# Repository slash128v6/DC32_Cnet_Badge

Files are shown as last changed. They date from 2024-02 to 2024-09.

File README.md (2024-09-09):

# DC32 CompuNet Badge 
## Description
The **Fony Bitman** by CompuNet is a cutting-edge, compact, and highly versatile device designed to seamlessly integrate with modern lifestyles. This device harnesses the robust capabilities of the ESP32 microcontroller, known for its high performance, low power consumption, and advanced wireless connectivity features.

*Key Features:*

Arduino-based ESP32 Microcontroller: At its core, the **Fony Bitman** features Wi-Fi and Bluetooth connectivity, as well as high-fidelity mono sound with redundant output (a second speaker).

Customizable and Expandable: The **Fony Bitman** by CompuNet is highly customizable, allowing developers to create tailored applications and features. Its expandable nature supports various sensors and modules, enhancing functionality for specific use cases. If you don't like how it works, re-engineer accordingly.

This device is not UL listed, certified, warranteed or recommended for anyone that is adverse to sharp, dangerous objects. As with all electronics projects, unplug when not in use and store safely to avoid fires, spontanious combustion, itching or burning sensations. 

Do not taunt the **Fony Bitman**.

## Badge Operation

The power switch selects battery power or USB power. USB power will charge the battery. The battery must be sufficiently charged for battery operation. If the badge does not operate on battery power let it charge via USB. There is a battery “gas gauge” on the charge module that is viewable from the front of the board.

From your phone connect to Bluetooth device “FONY BITMAN”. Sound should play through the speakers and the LED strips should react to the music. The touch pads on the top front of the badge should act as music and volume controls.

## Part 1: Badge Assembly

### Badge Parts List

| QTY | Description |
|-----|---|
| 1 | 2 pos CONN HEADER  |
| 1 | switch |
| 1 | 6 pos CONN HEADER  |
| 1 | 16 pos CONN HEADER |
| 1 | ESP-32 |
| 2 | LED Stick |
| 1 | Amp |
| 2 | speaker |
| 1 | charge module |
| 3 | foam tape |
| 1 | battery |

### Step 1: Front view:

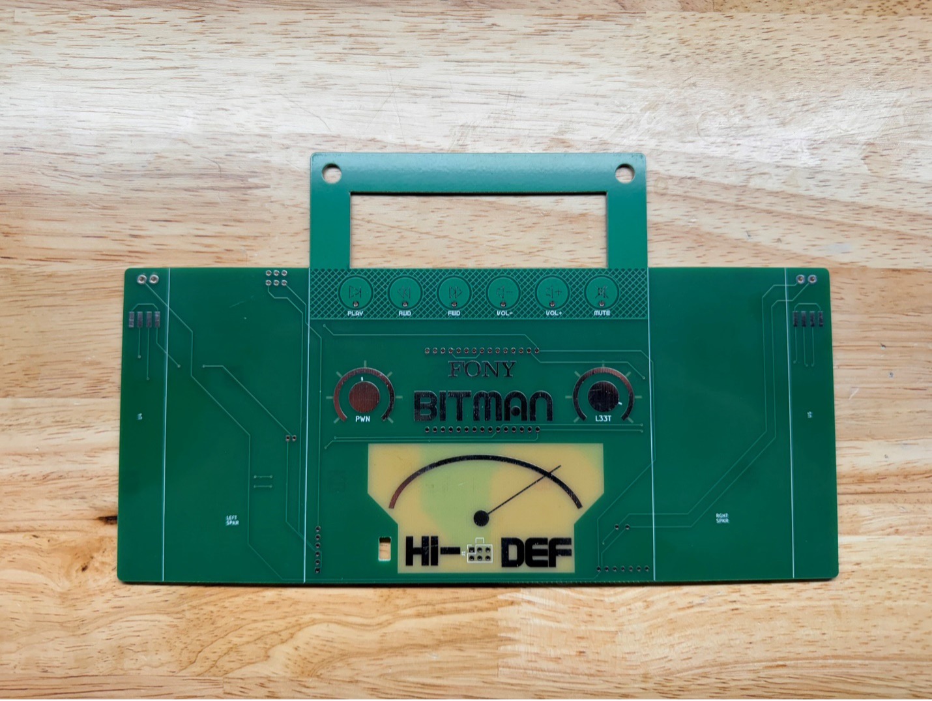
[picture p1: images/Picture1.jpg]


### Step 2: Rear View

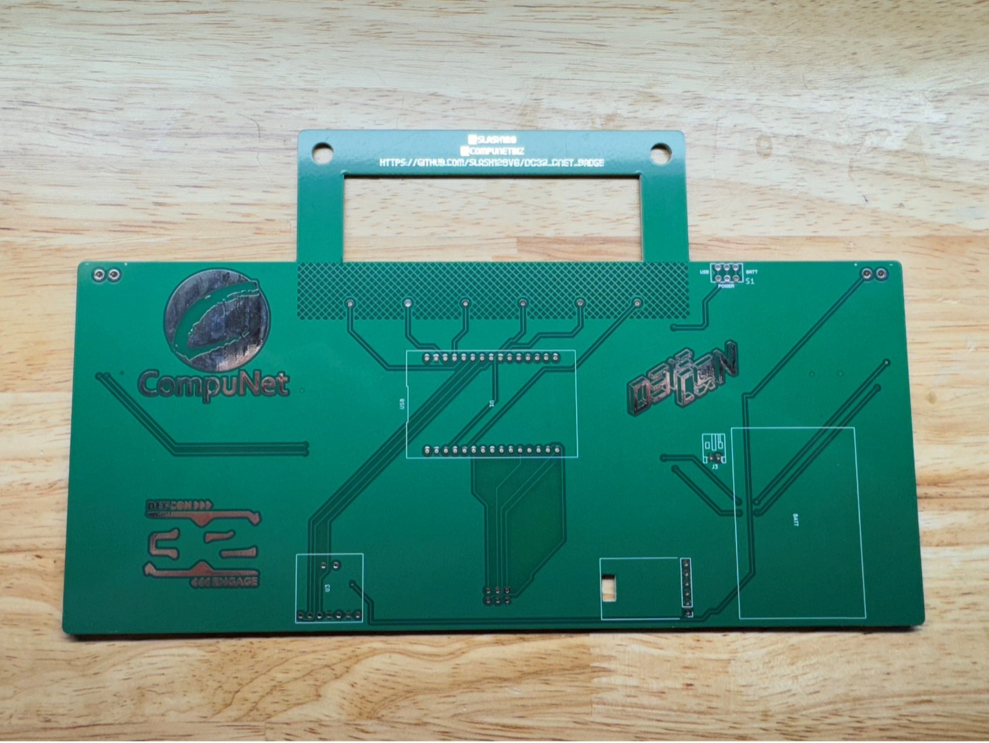
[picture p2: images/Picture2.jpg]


### Step 3: Solder LED strips to front

The DI (Data In) side connects to the badge pads.

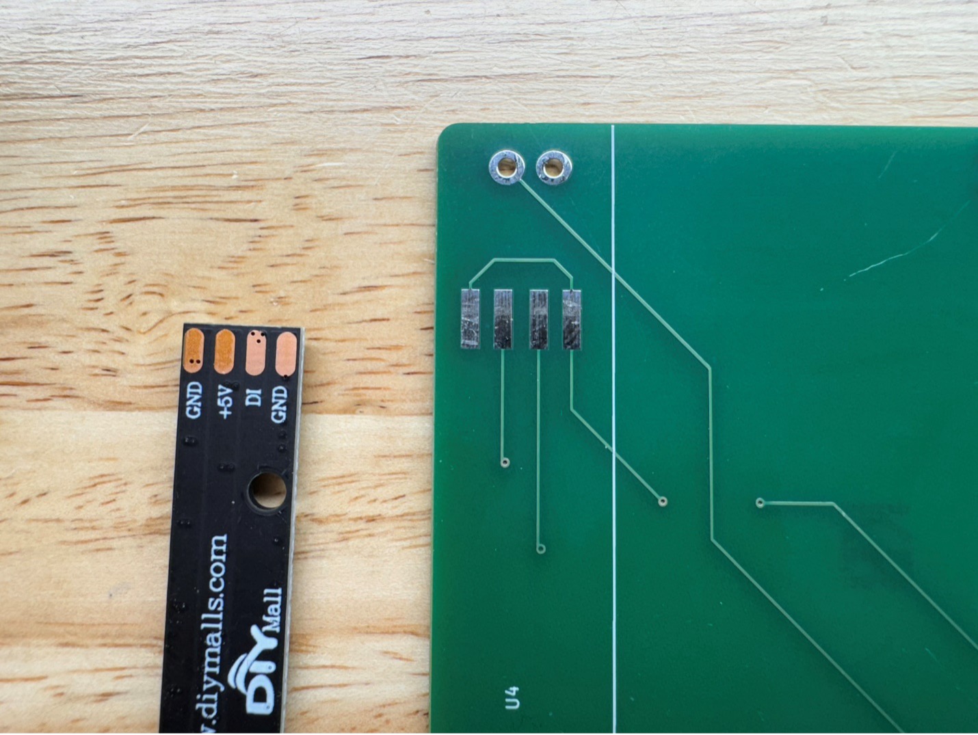
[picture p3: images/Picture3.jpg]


### Step 4: Tin the LED & badge pads

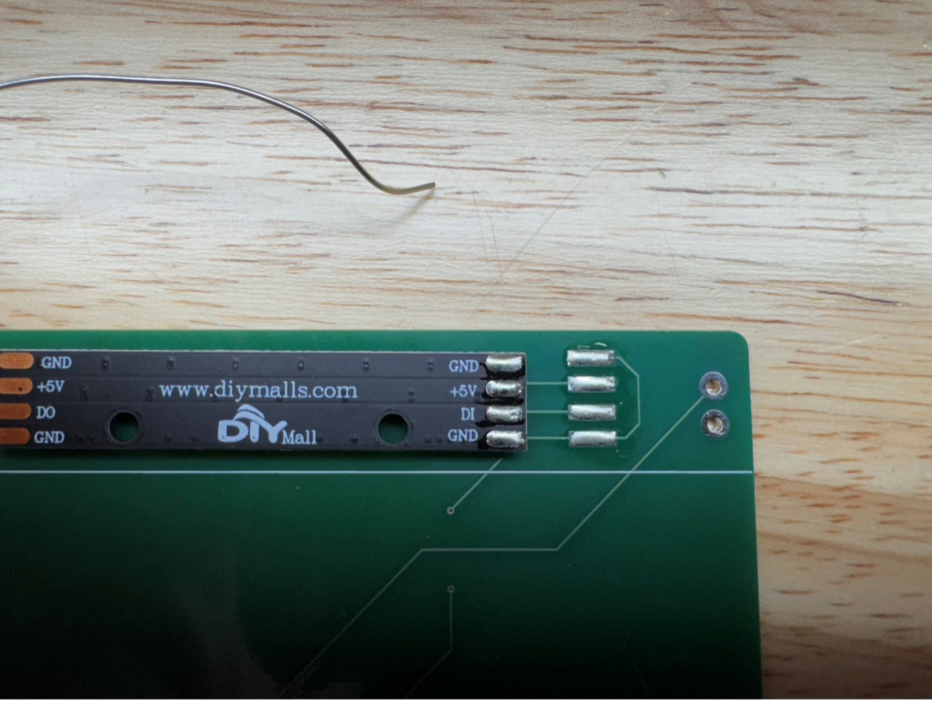
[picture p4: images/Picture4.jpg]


### Step 5: Apply first LED

Line up the LED strip pads on the badge pads leaving the ends of the badge pads exposed so you can heat them up with your soldering iron. It’s a little tricky but you should be able to get the solder to flow and insert some solder from the sides of the pads to connect the pads. Try to keep the LED strip straight. 

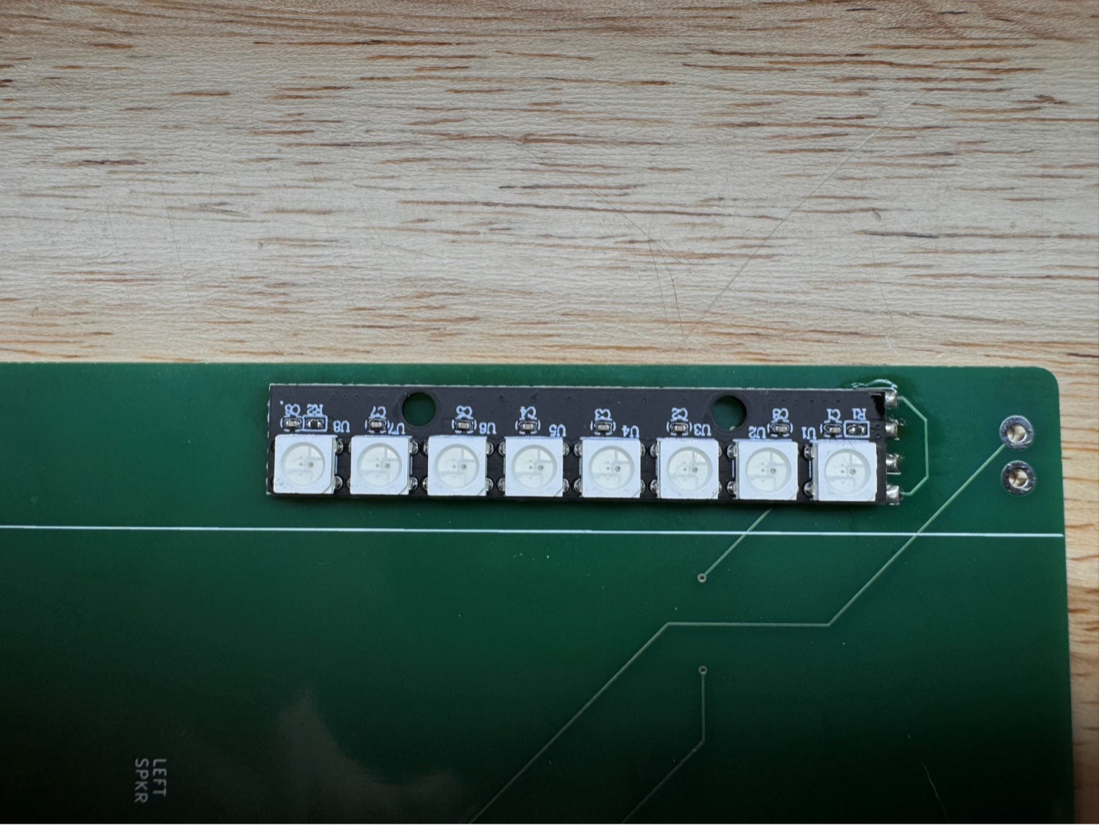
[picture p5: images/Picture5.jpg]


### Step 6: Repeat for the second LED strip

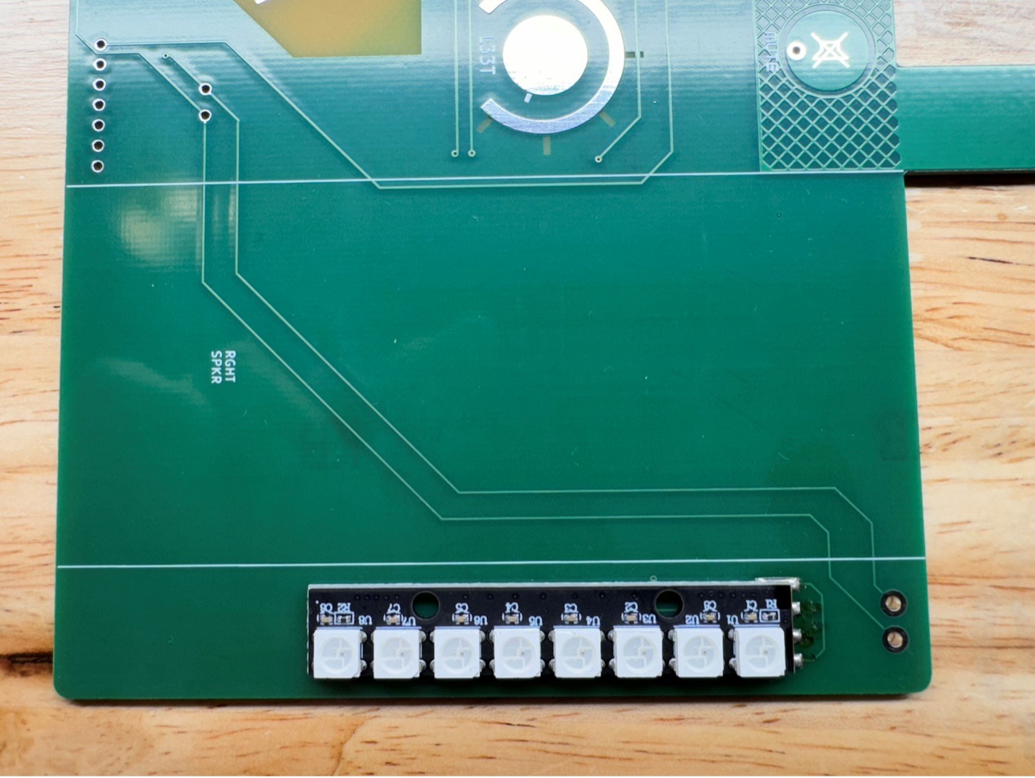
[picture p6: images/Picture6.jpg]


### Step 7: Power Switch

Solder the power switch on the back with the switch tab facing up

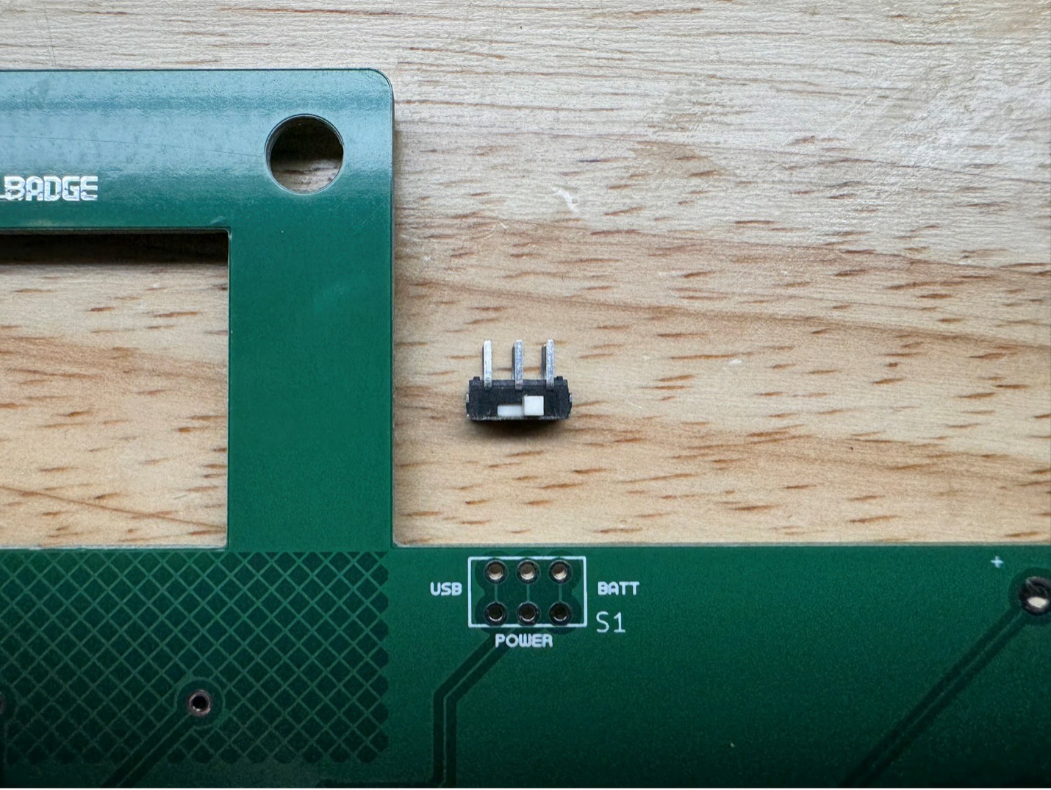
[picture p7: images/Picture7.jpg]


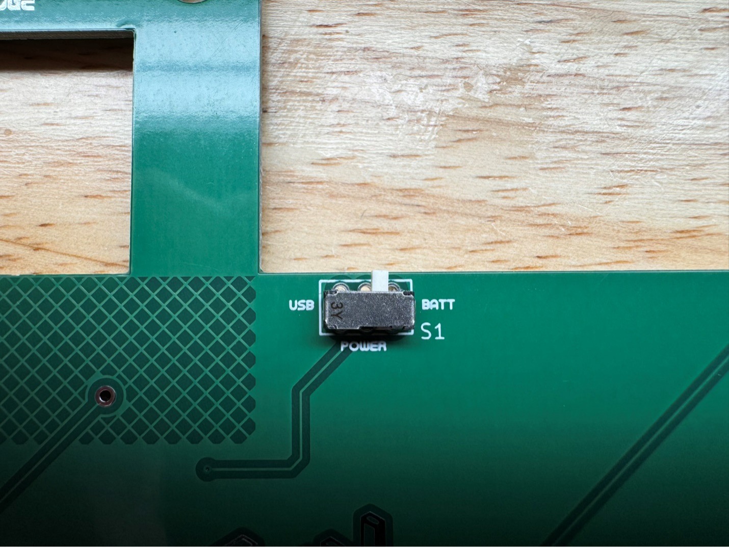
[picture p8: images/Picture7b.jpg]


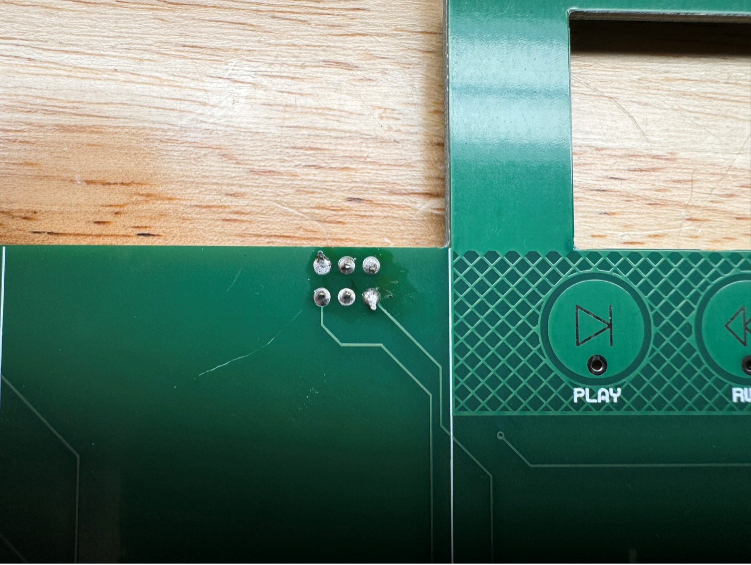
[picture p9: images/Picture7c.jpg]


### Step 8: Solder the SAO connector

Solder the SAO connector with the tab up matching the outline keeping it straight and parallel to the bottom oedge of the badge

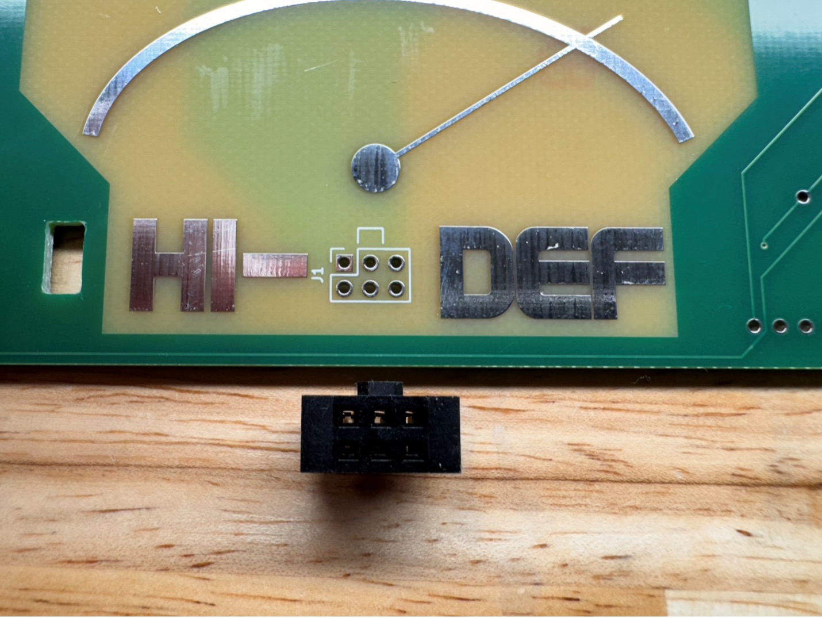
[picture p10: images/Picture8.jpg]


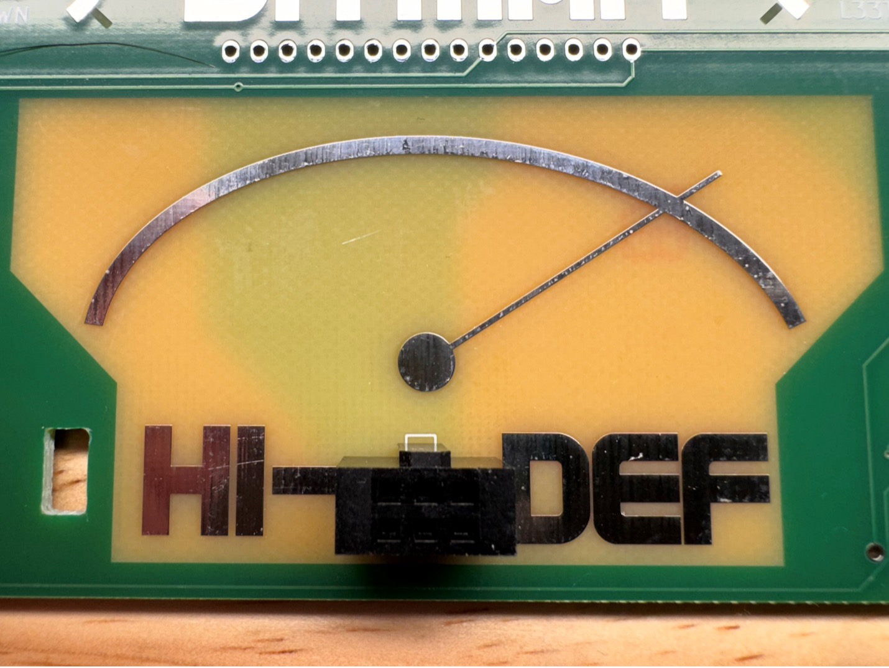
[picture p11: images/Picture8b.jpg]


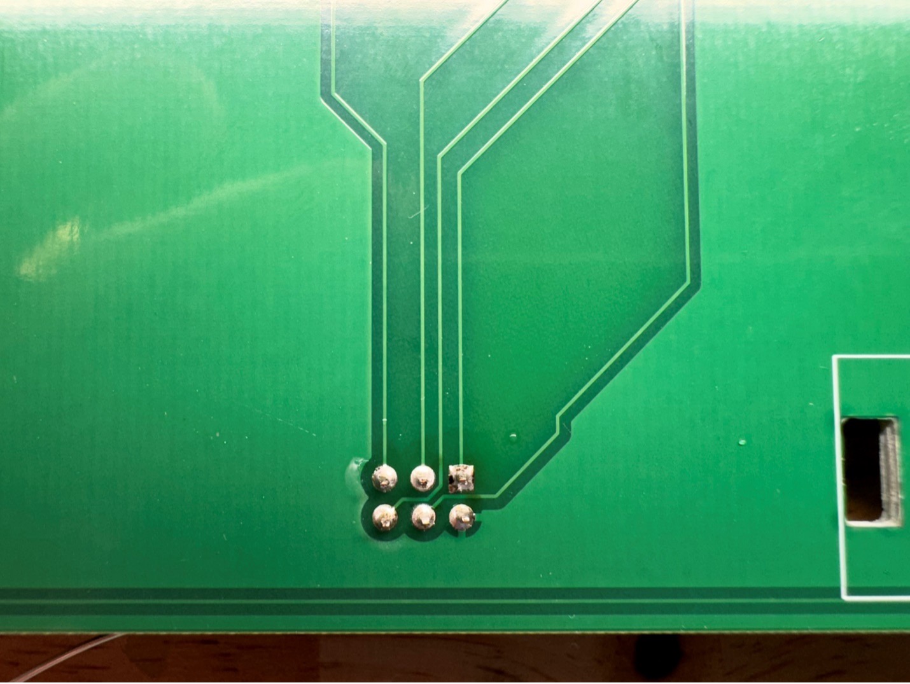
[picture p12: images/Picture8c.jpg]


### Step 9: Battery Charger Module

Locate the battery charger module and pin header and cut off 6 pins

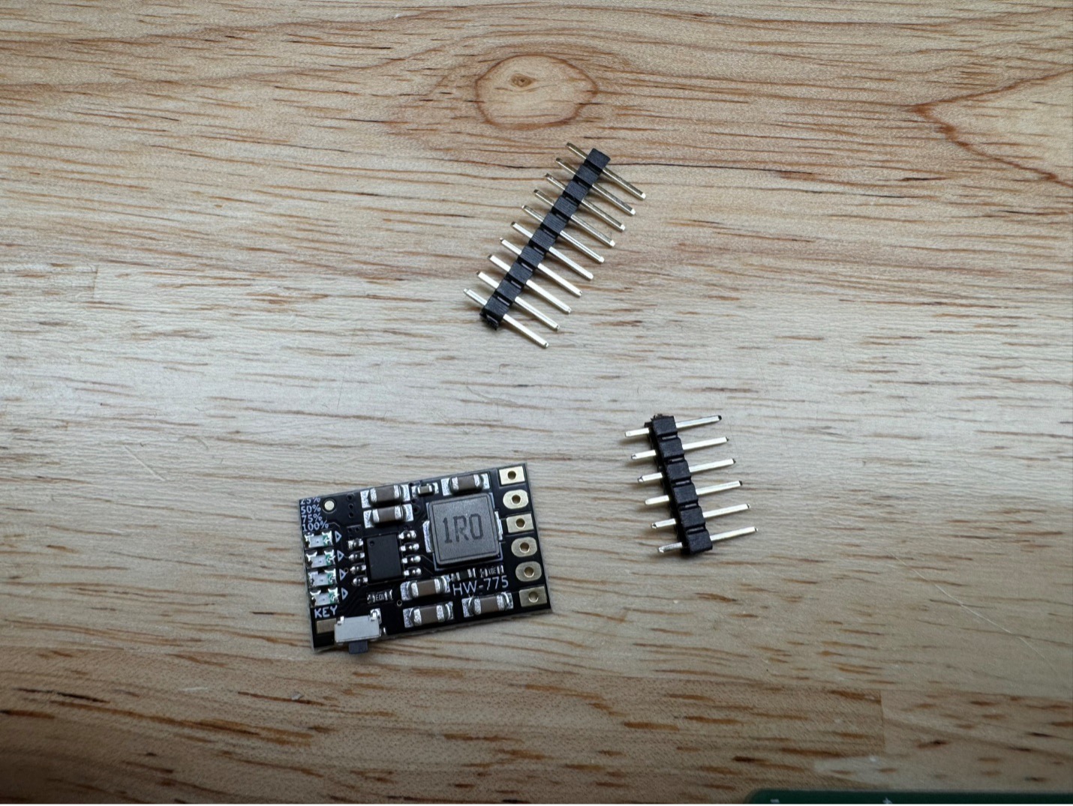
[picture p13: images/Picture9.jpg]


### Step 10: Solder the module header

Solder the 6 pin header to the charge module with the short pins protruding through the white silkscreen side of the charge module

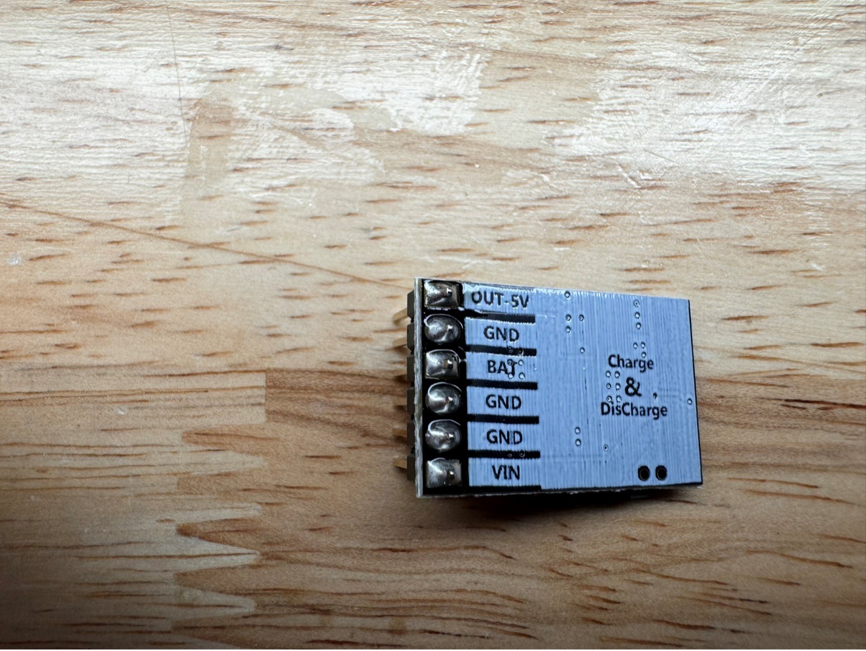
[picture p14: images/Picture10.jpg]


### Step 11: Attach module to the badge

Solder the charge module to the back of the badge

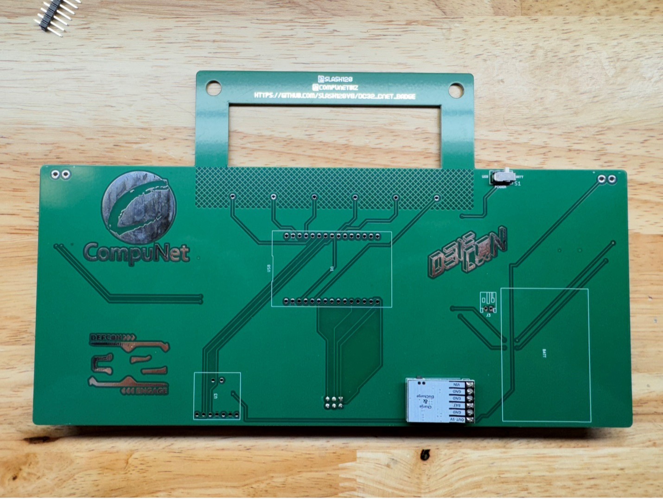
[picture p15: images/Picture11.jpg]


### Step 12: Verify LED visibility

The charge module battery level LEDs should be visibile through the front of the badge

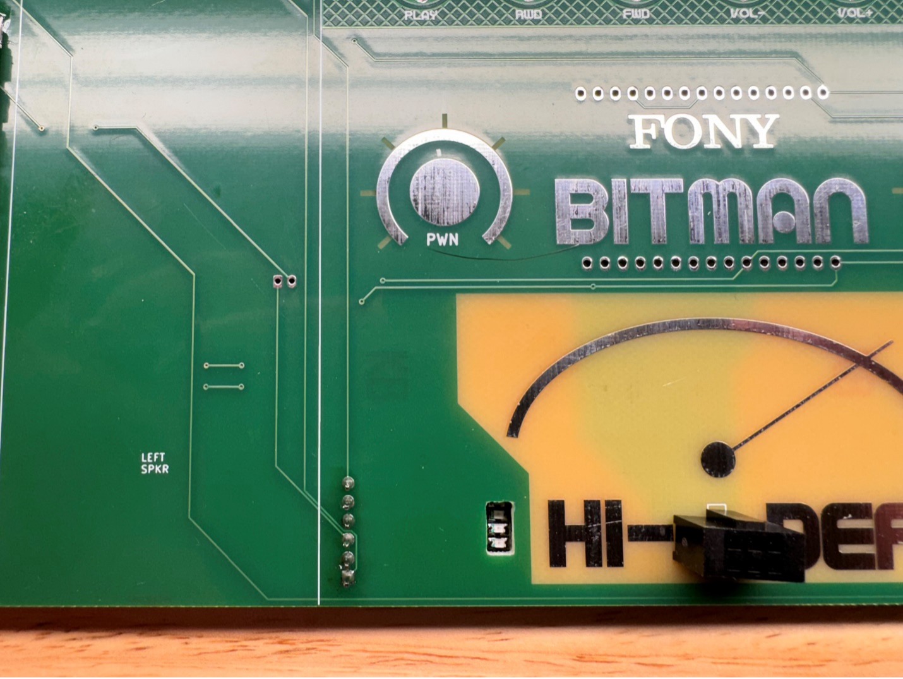
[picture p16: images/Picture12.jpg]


### Step 13: Amplifier module

Locate the amplifier module and pin header, the green screw terminal is not needed and can be discarded

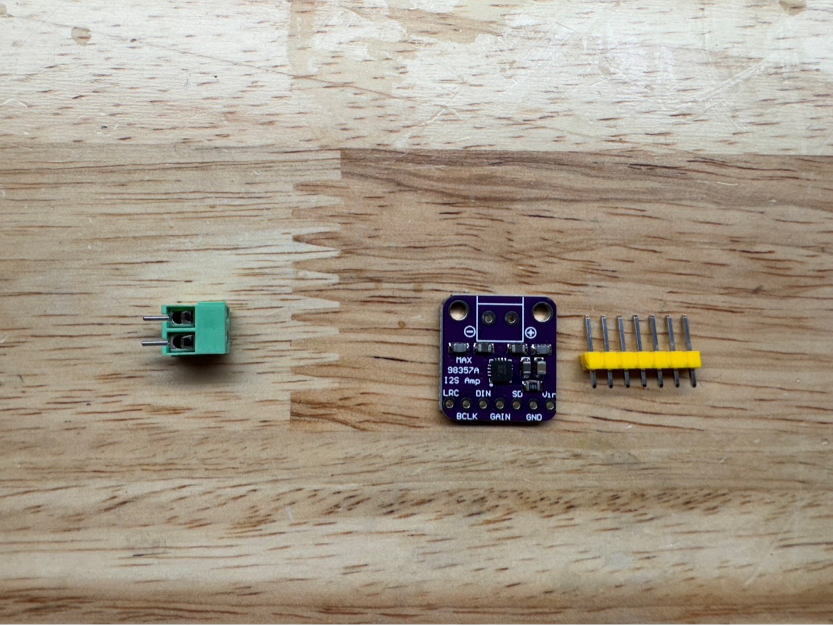
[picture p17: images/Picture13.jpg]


### Step 14: Solder amp header

Solder the pin header to the amplifier with the short side of the pins protruding through the silkscreen pin label side of the amplifier module

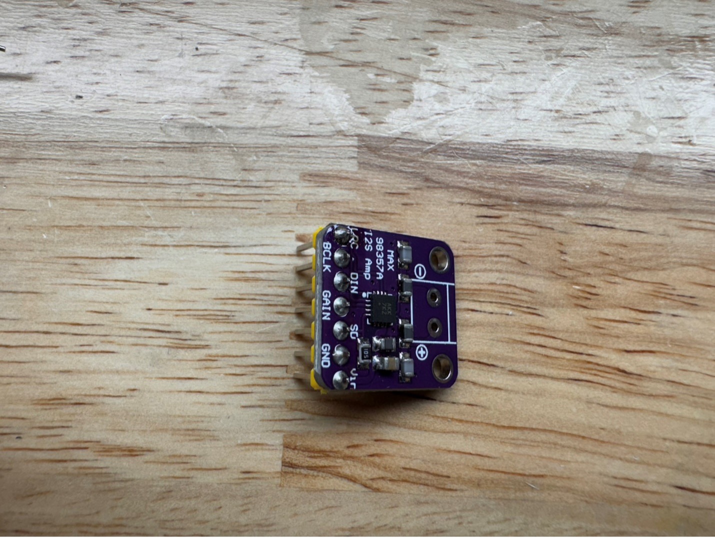
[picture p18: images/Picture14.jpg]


### Step 15: Attach pins to speaker outs

15)	Cut 2 more single pins and solder them to the speaker outputs with the short side protruding through the silkscreen pin label side of the amplifier module

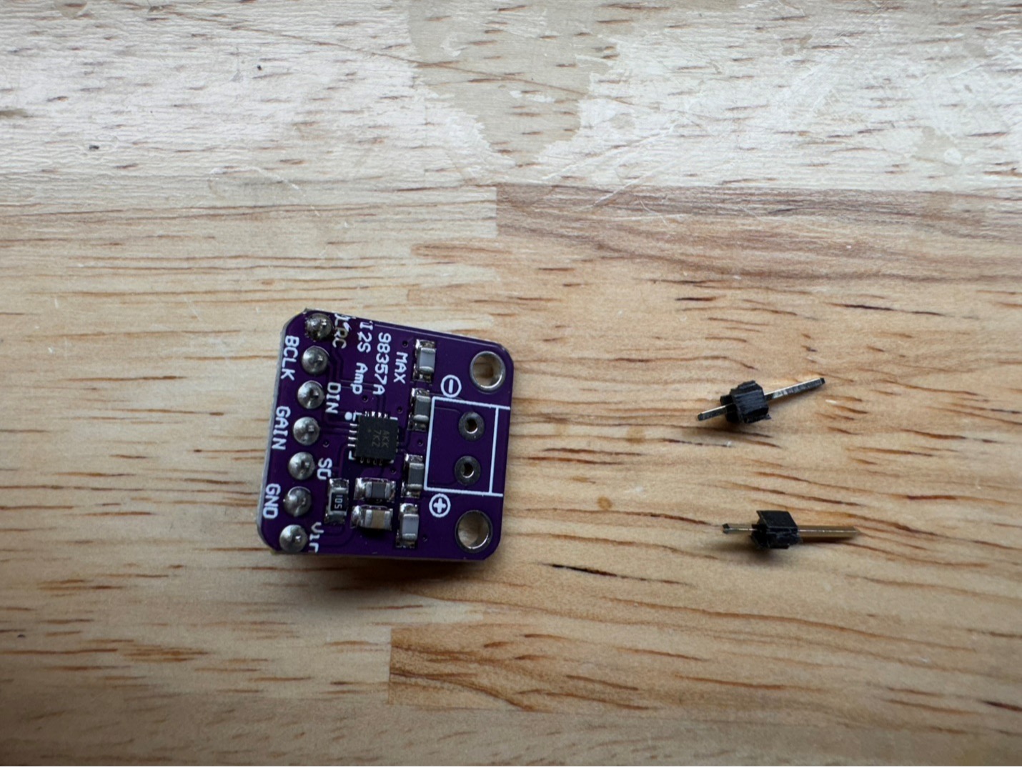
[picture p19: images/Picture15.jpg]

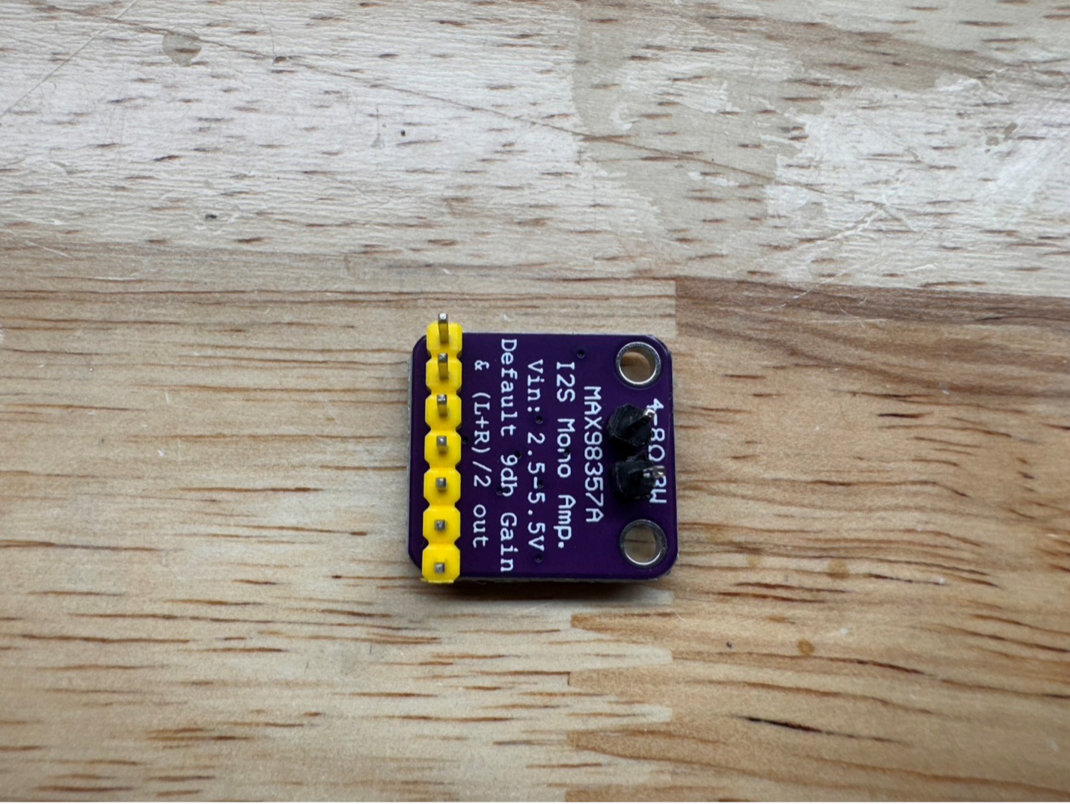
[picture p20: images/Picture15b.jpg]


### Step 16: Attach amp module to badge

Solder the amplifier module through the back of the badge

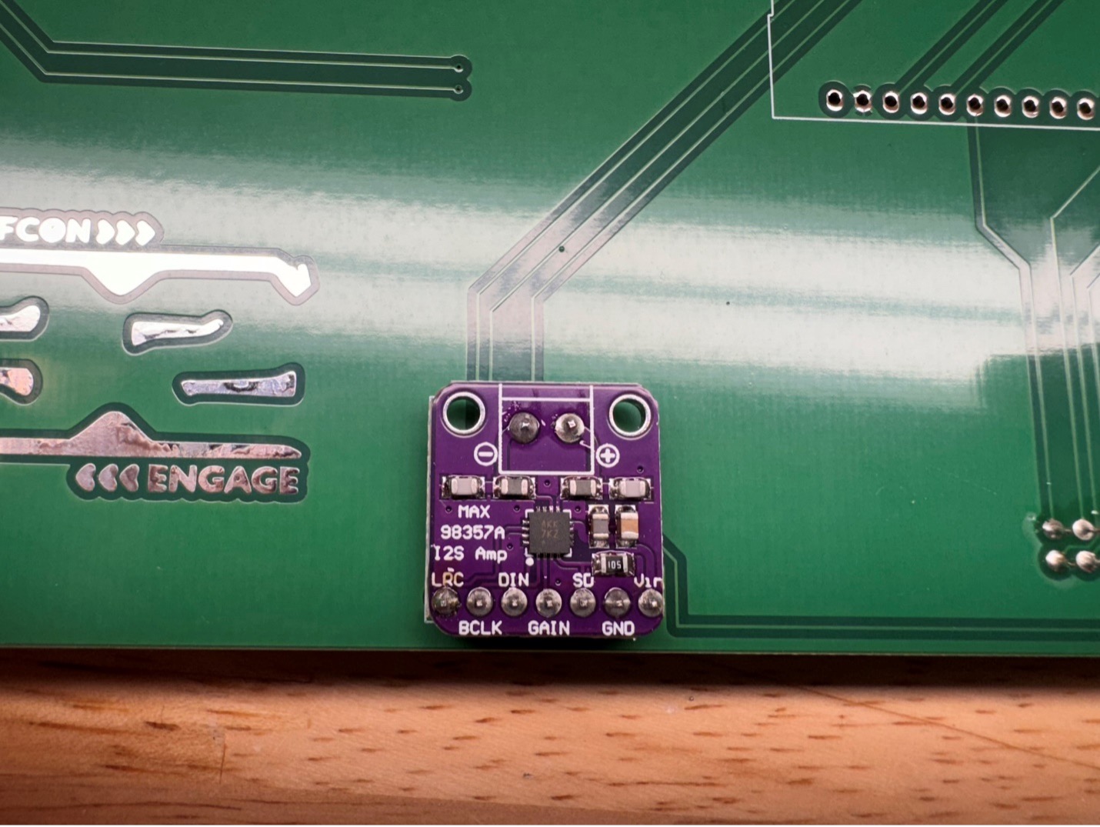
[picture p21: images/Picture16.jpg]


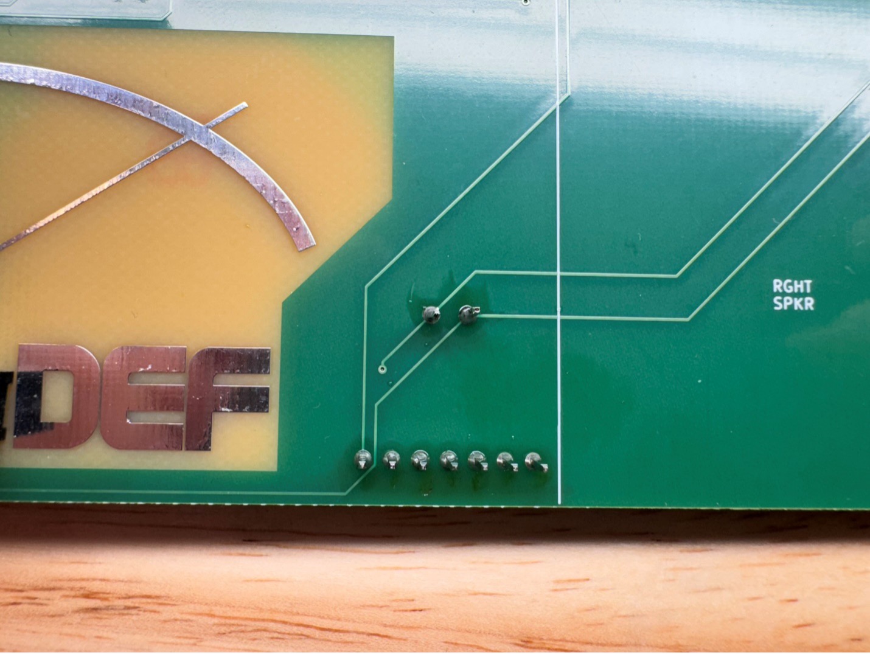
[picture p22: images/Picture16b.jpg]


### Step 17: ESP32 Module

Solder the ESP32 module to the back of the badge with the USB connector oriented to the silkscreen outline which should face the CompuNet logo

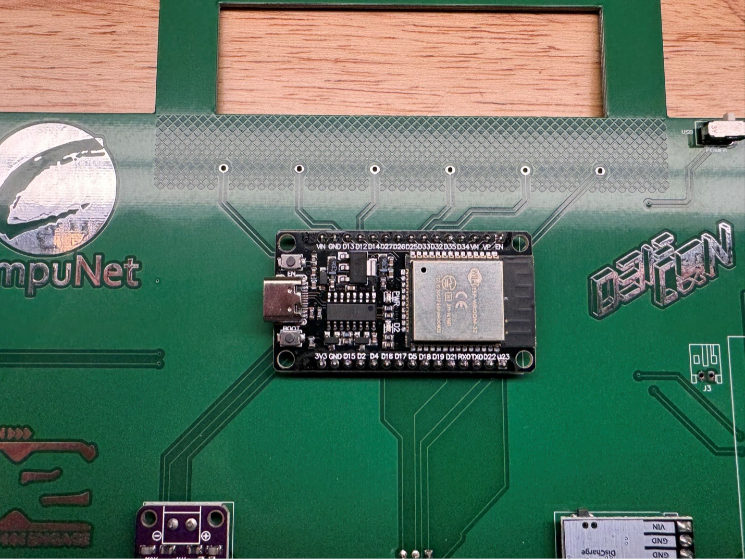
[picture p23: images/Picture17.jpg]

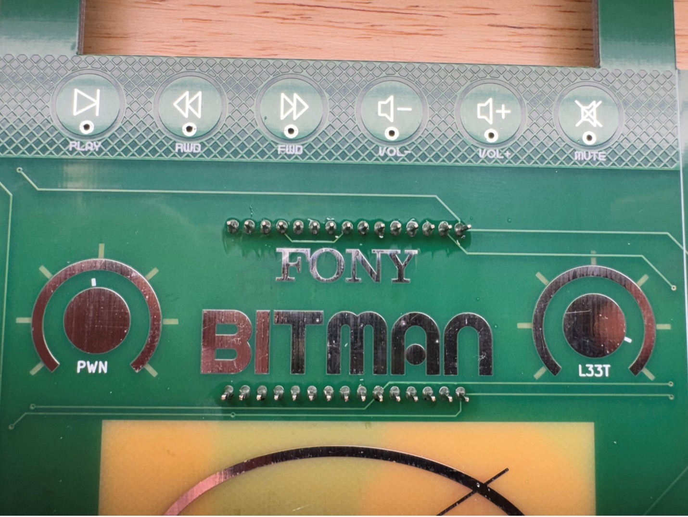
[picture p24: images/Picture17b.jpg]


### Step 18: Battery Connector

Solder the battery connector to the back of the badge

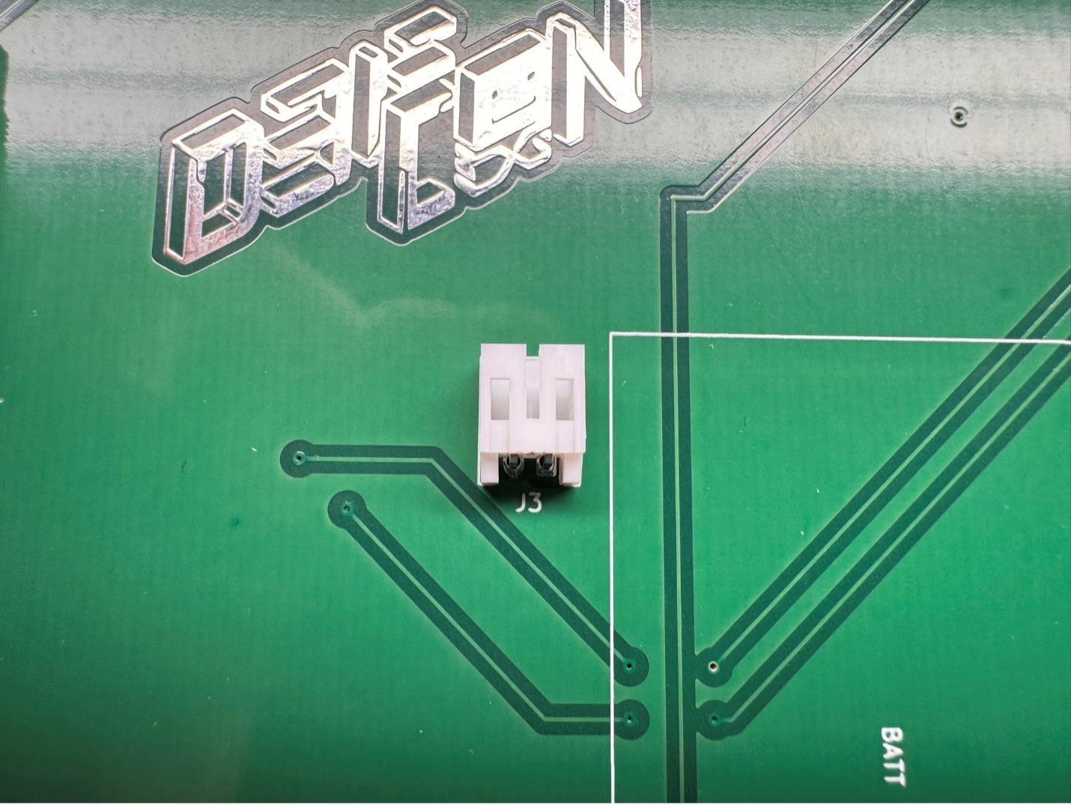
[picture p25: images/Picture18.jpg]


### Step 19: Speaker Wire

Trim the speaker wires leaving a few inches and run the speaker wires through the holes as shown for strain relief 

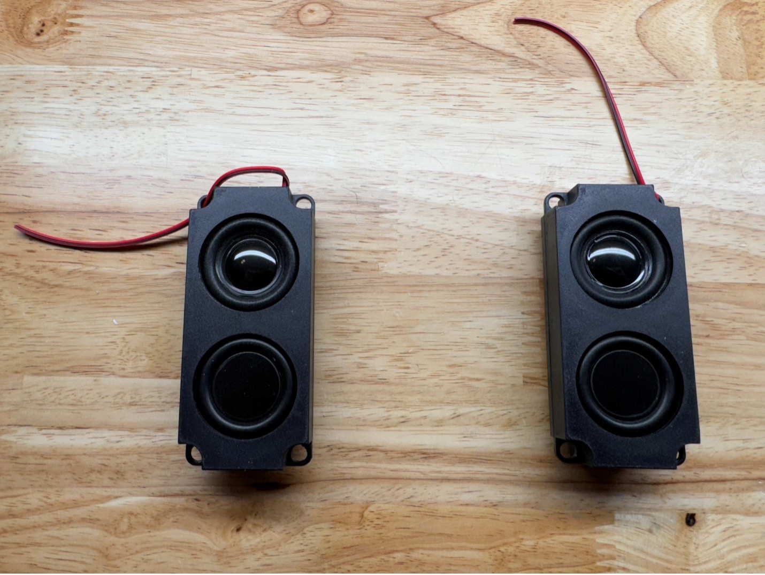
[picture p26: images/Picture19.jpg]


### Step 20: Tape Speakers

Cut two pieces of double-sided foam for speaker mounting (leave enough for a third piece for battery mounting)

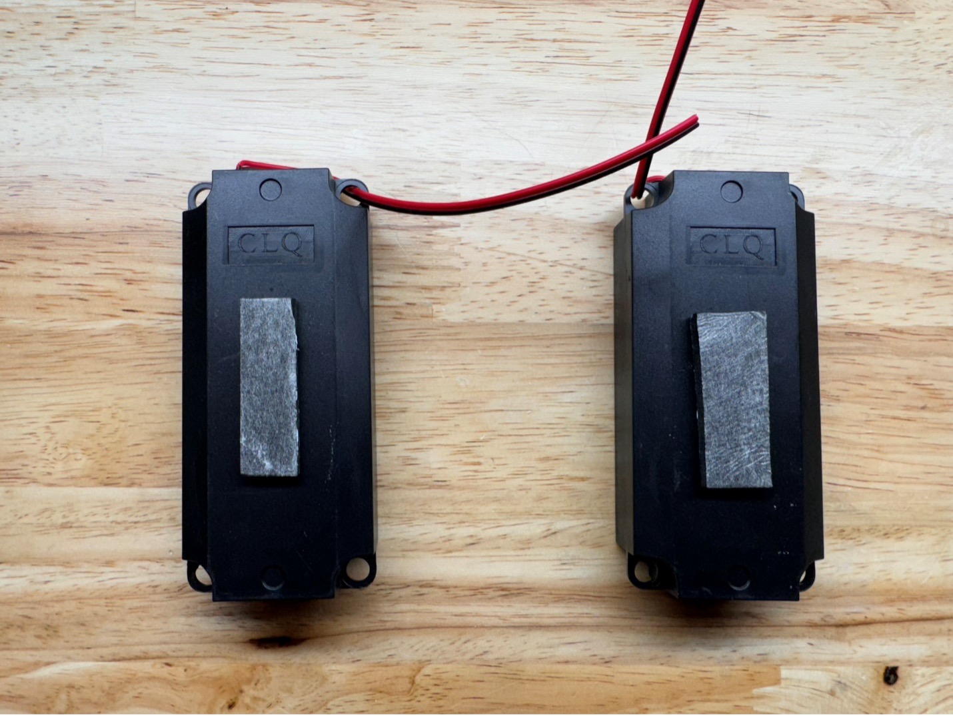
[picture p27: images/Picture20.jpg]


### Step 21: Attach Speakers

Mount the speakers to the badge using the foam tape by standing the badge and speakers upraight before pressing them together so it balances and doesn’t tip over

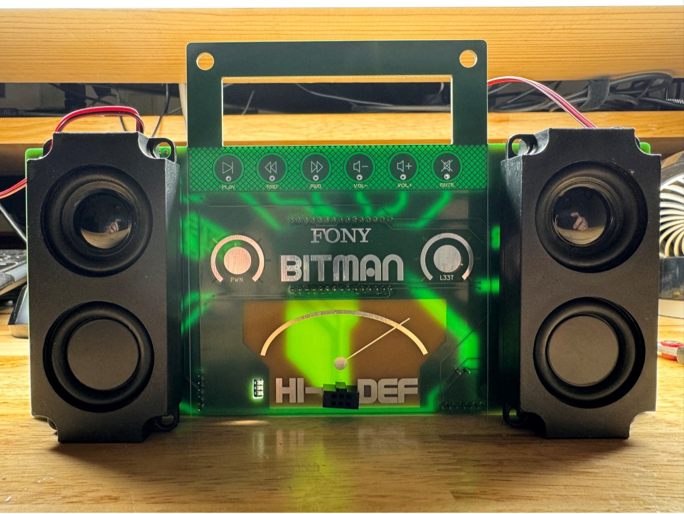
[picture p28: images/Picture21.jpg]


### Step 22: Speaker Wires

Split and trim the speaker wires to solder to the badge

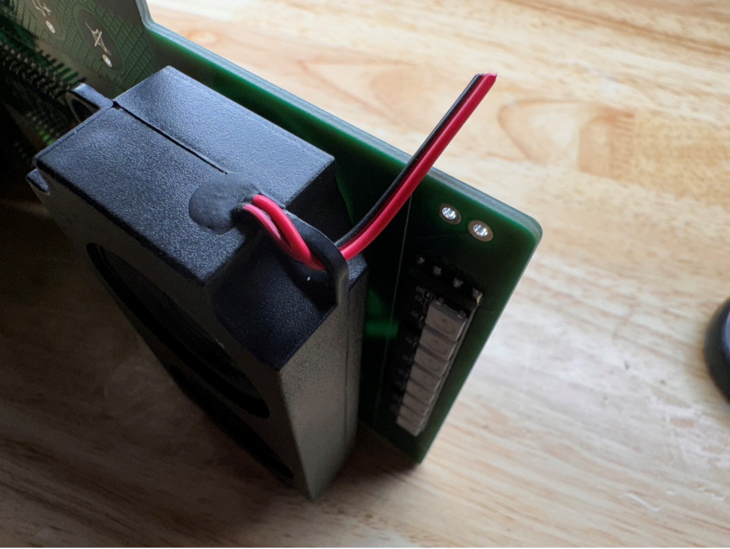
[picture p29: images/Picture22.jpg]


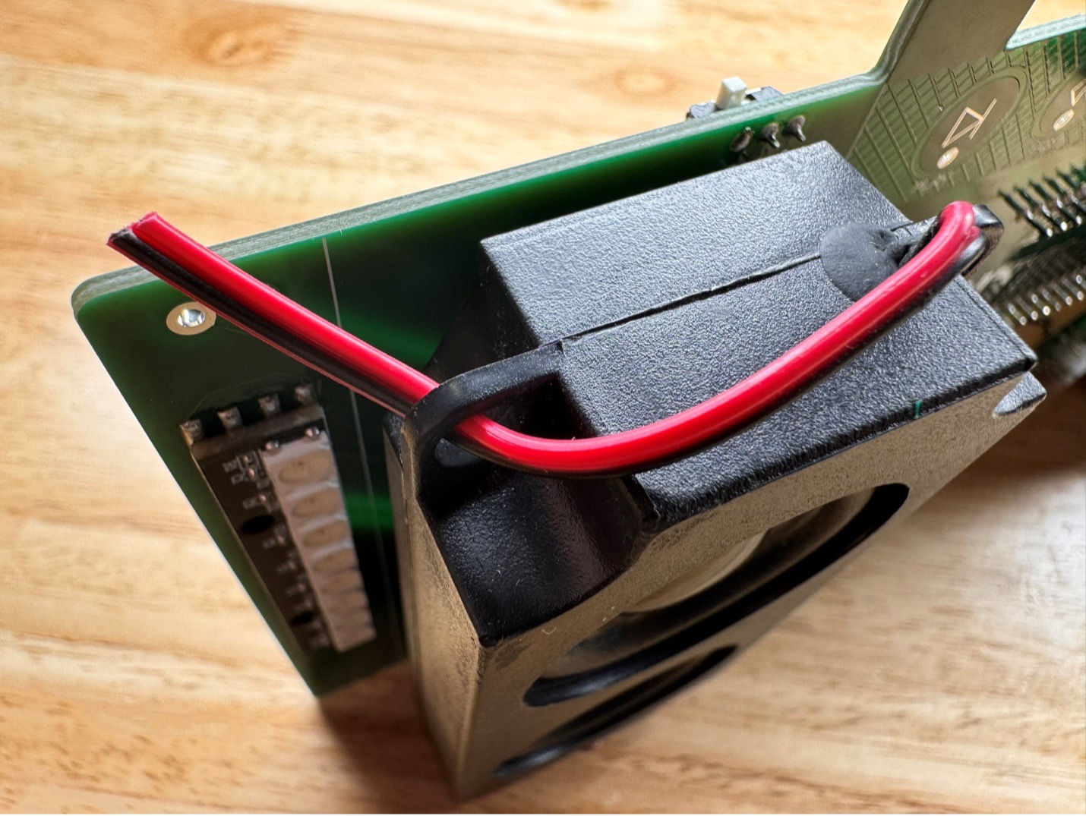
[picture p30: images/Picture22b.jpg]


### Step 23: Solder Speaker Wires

Solder the speaker wires to the badge noting polarity – red to (+) and black to (-)

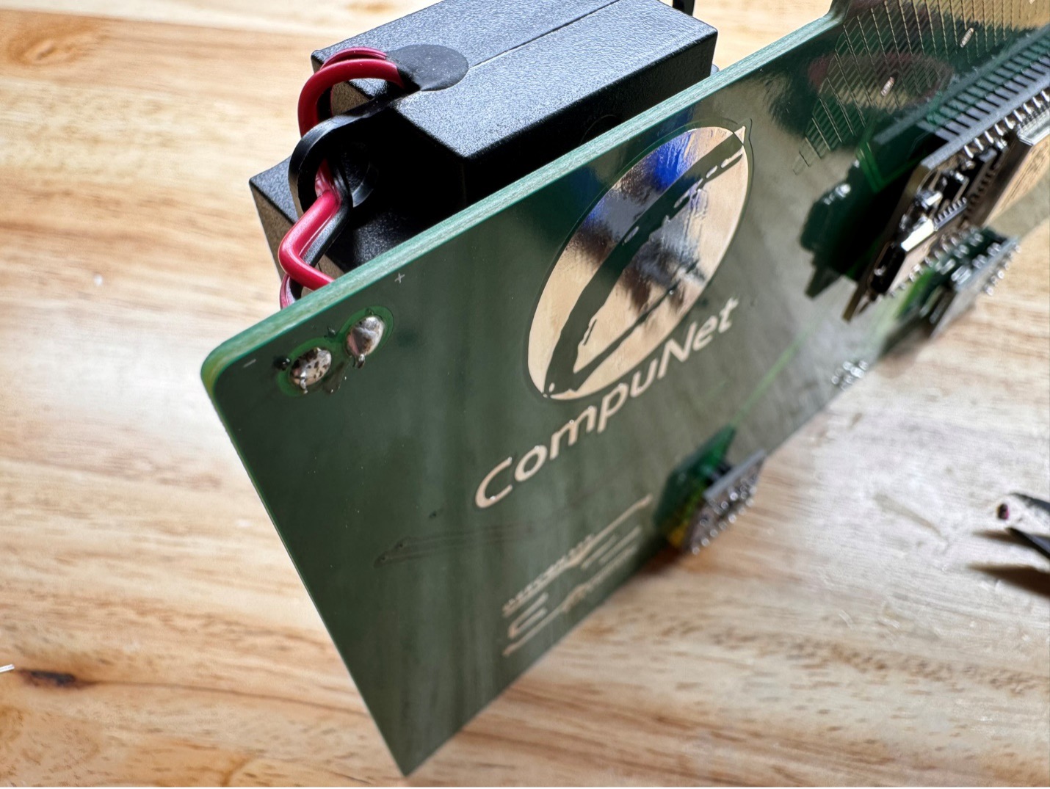
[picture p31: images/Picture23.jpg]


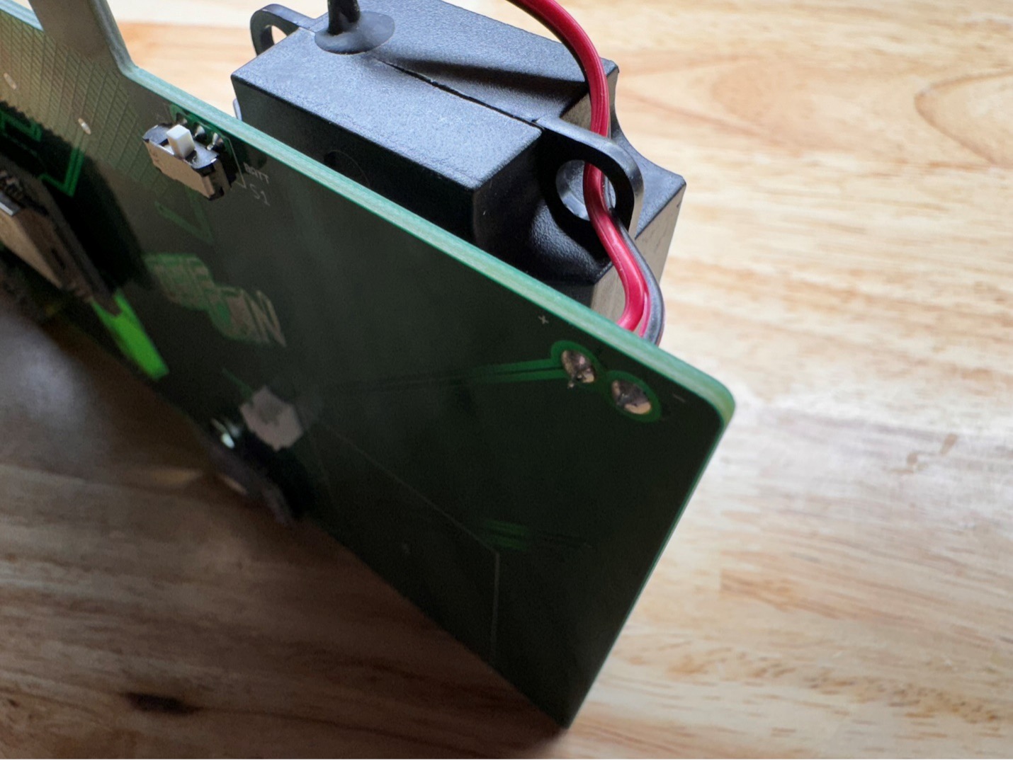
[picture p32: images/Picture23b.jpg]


### Step 24: Power pigtail

Locate the JST PH 1.25 and JST PH 2.0 pigtail leads and 1 piece of heat shrink

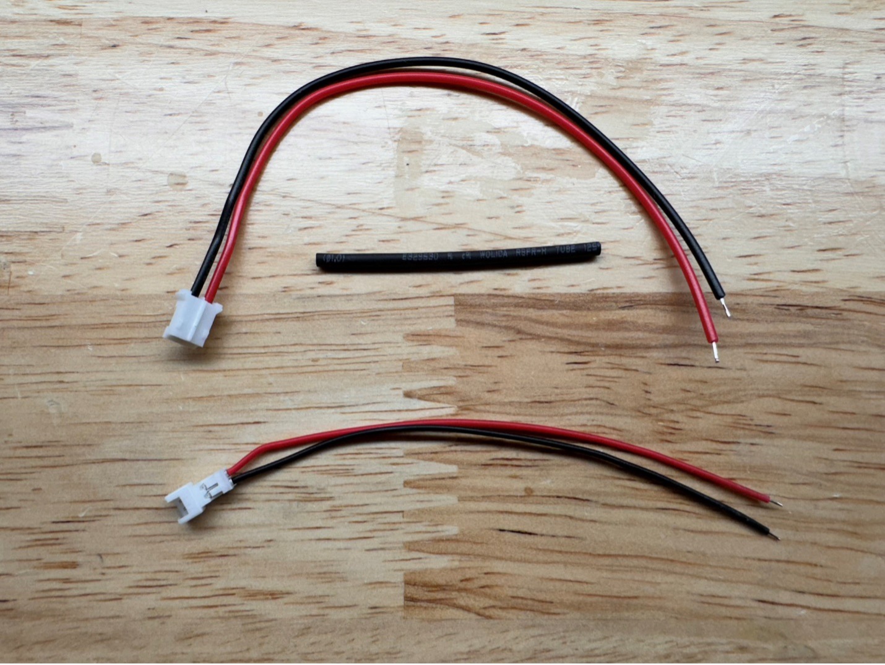
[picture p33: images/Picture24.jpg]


### Step 25: Polarity Check

_***Important!***_

Verify Polarity!

Due to a part change with the JST PH 2.0 pigtail please confirm that the wires are in the correct position matching the photo above. If they are opposite then you need to swap them around by carefully lifting up the plastic tabs with tweezers, removing each wire, then slide them back in to the opposite side. 

**ASK IF YOU NEED HELP WITH THIS. PERFORMING THIS STEP INCORRECTLY WILL DAMAGE YOUR BADGE AND COULD BE A FIRE HAZZARD. 

PROCEED WITH CAUTION!!**

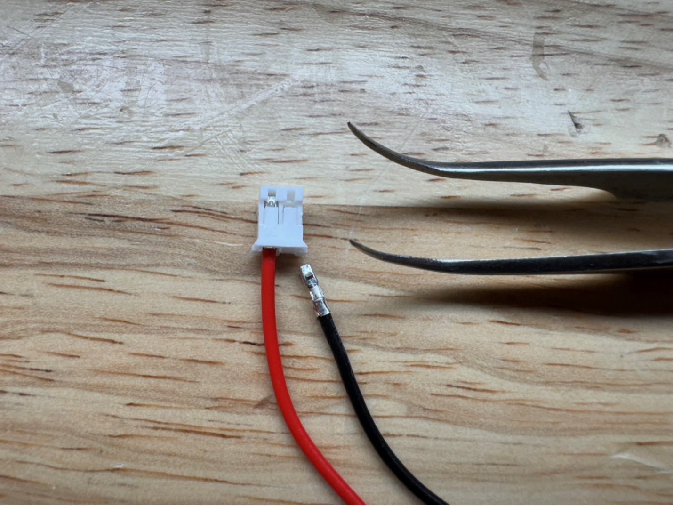
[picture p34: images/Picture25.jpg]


### Step 26: Pigtail

Slip the 2 pieces of heat shrink onto the JST PH 2.0 pig tail (fatter wires), then strip and tin the ends

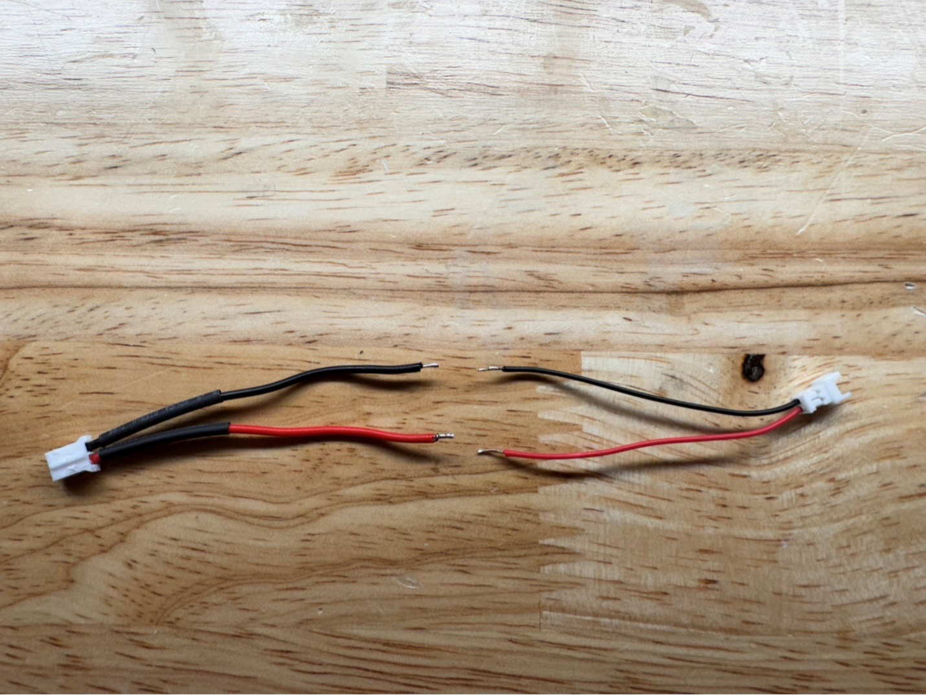
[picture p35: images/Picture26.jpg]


### Step 27: Solder the Cables

Solder the wires together RED to RED and BLACK to BLACK, a set of “helping hands” can be helpful 😊

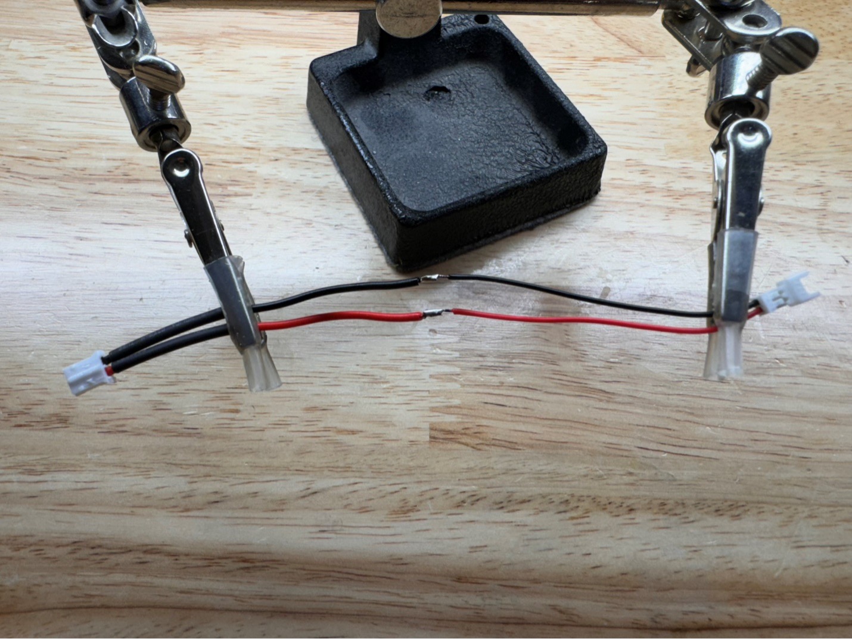
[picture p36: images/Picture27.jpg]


### Step 28: Apply Heatshrink

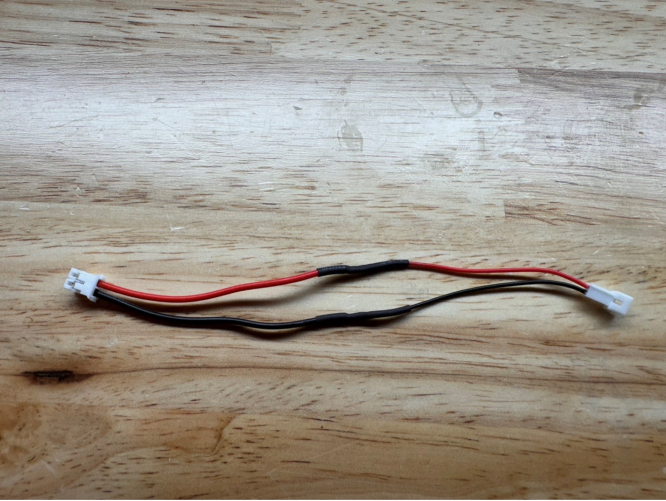
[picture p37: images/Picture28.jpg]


### Step 29: Badge Adhesive

Place the last piece if the double sided tape in the battery location on the back of the badge

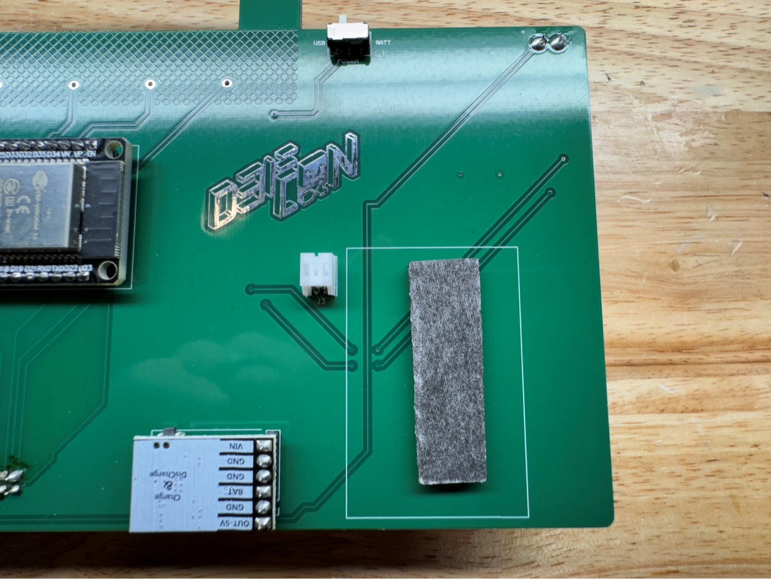
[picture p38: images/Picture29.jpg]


### Step 30: Battery Leads

Route the battery leads using the pigtail connector, the leads can be tucked under the edges of the battery.

**Verify polarity is correct before connecting. If you're not sure, please ask.**

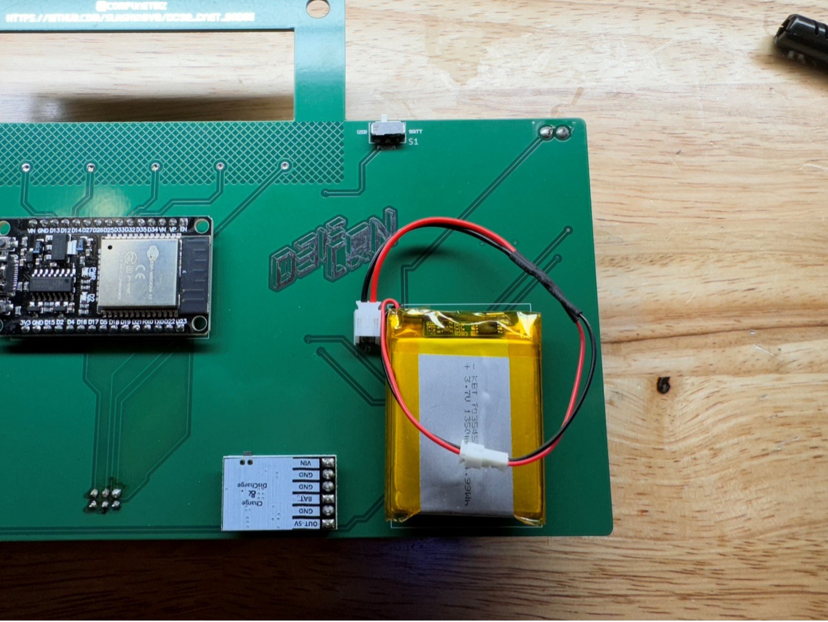
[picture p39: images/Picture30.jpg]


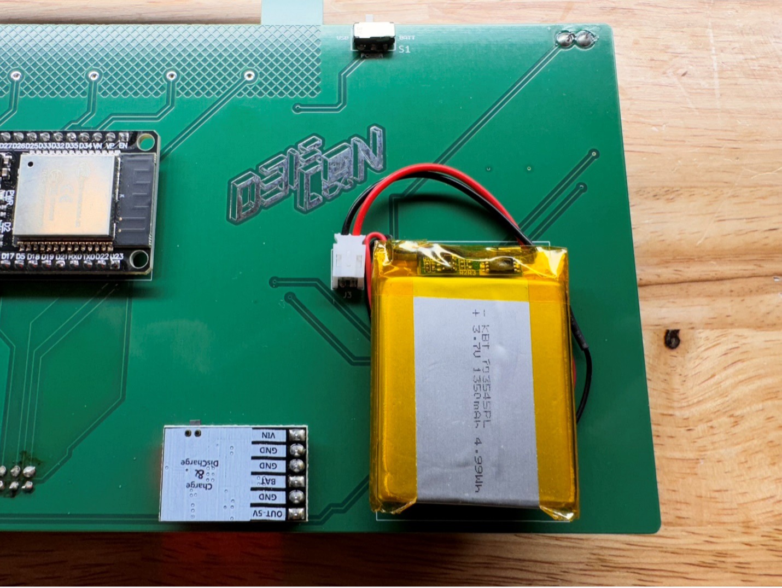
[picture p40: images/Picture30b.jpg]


## Part 2: Badge Programming

Check out the badge programming doc [here](https://github.com/slash128v6/DC32_Cnet_Badge/blob/main/Docs/programming.md)

## Part 3: SAO Builds

Check out the SAO build doc [here](https://github.com/slash128v6/DC32_Cnet_Badge/blob/main/Docs/sao.md)

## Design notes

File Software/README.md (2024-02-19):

# DC32_Cnet_Badge - Software
 Developed in Microchip Studio with Visual Micro, but can be edited & uploaded with Arduino IDE.

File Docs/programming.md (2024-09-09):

## Part 2: Badge Programming

Programming the Microcontroller
1)	Download the badge repo and unzip somewhere on your local drive:
a.	https://github.com/slash128v6/DC32_CNet_Badge
2)	Open the Arduino badge sketch from the Software directory in the Arduino IDE.
3)	Add the following to "Additional Boards Manager URLs" in preferences:
a.	https://espressif.github.io/arduino-esp32/package_esp32_index.json

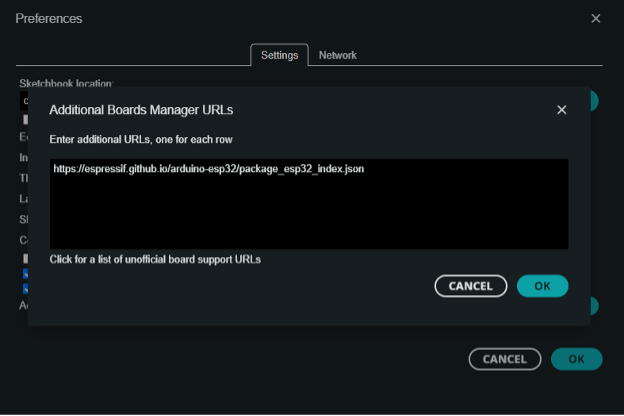
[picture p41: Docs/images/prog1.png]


4)	In Boards Manager search for esp32 and install "esp32 by Espressif Systems" version 2.0.12.

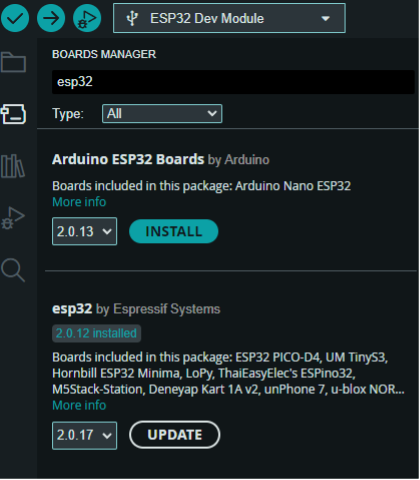
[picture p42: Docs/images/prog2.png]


5)	Search for and install the Adafruit Neopixel library version 1.12.0

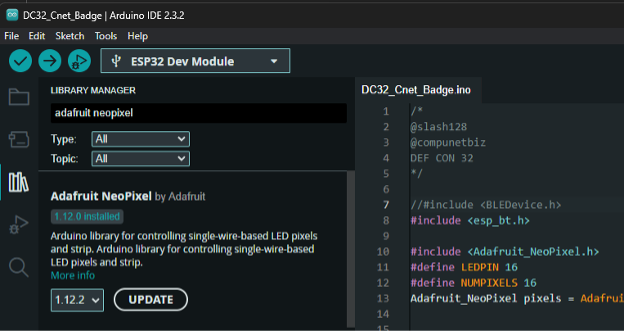
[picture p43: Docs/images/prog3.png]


6)	Install the ESP32-A2DP Bluetooth library from the pschatzmann folder via Sketch->Include Library->Add ZIP Library.

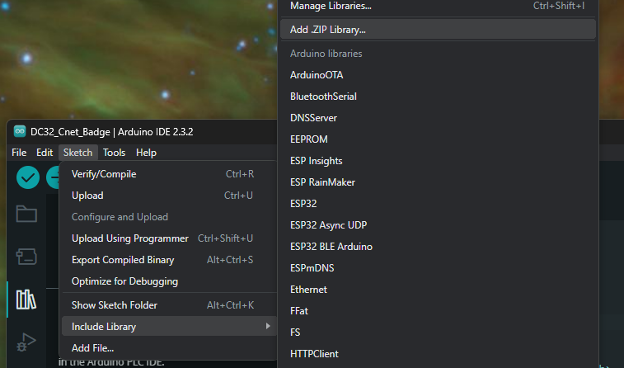
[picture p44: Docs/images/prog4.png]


7) Offer Slash128 a crisp high-five

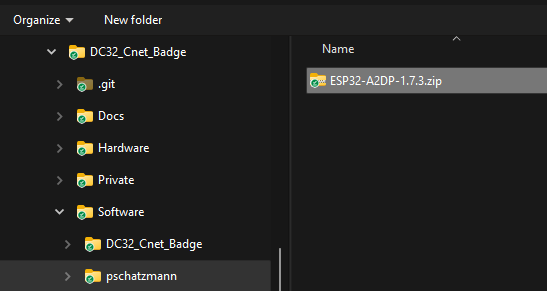
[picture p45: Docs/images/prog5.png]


8)	Set the power switch to USB and connect via USB data cable.

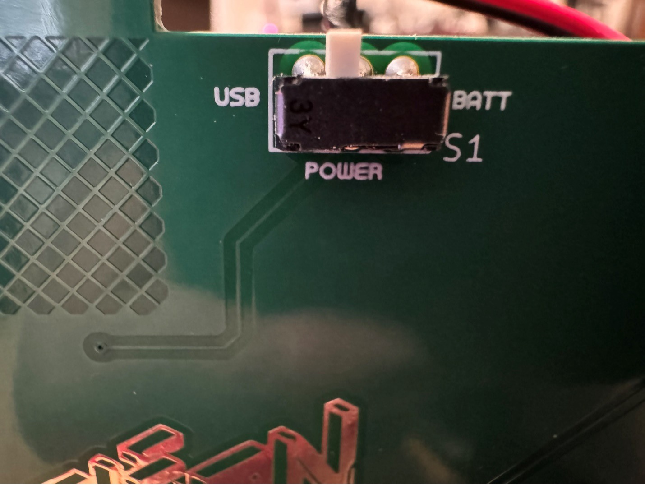
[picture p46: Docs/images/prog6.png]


9)	Note the COM port detected in Device Manager and select that port in the Arduino IDE.



10)	Click on the board selection, then “Select other board and port…” and choose ESP32 Dev Module on your connected COM port.

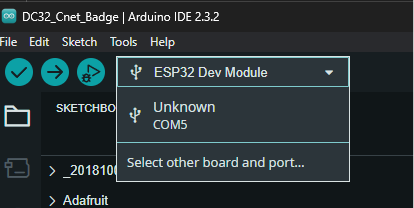
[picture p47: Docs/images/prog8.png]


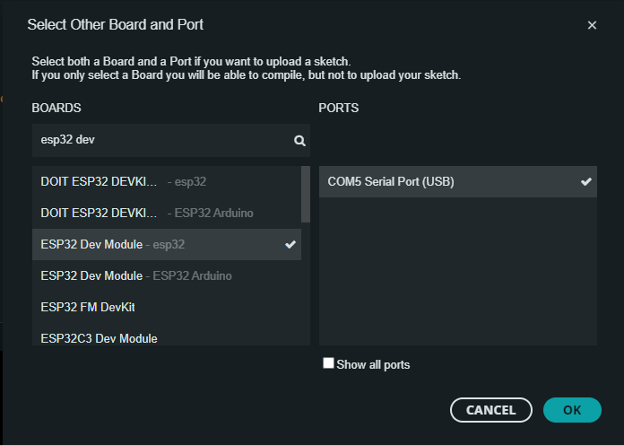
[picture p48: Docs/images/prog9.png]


11)	Confirm the upload speed is set to “921600”

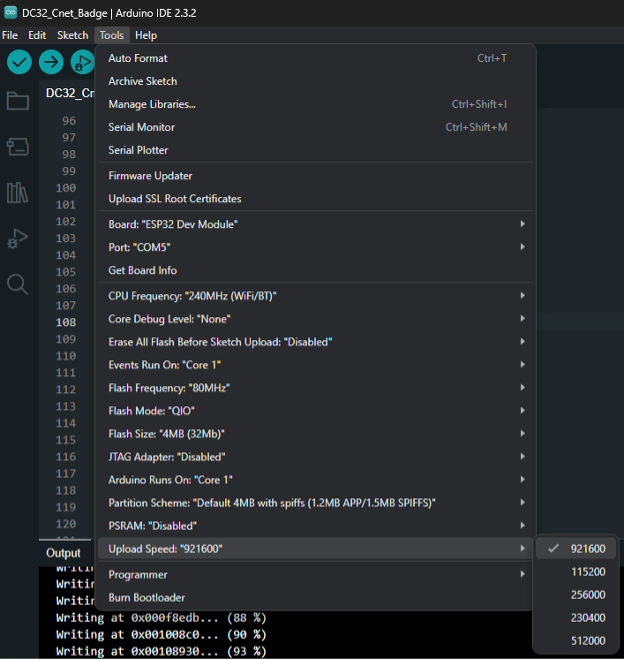
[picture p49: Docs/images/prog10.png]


12)	Ignore prompts to update libraries or boards. Newer versions are sometimes incompatible.

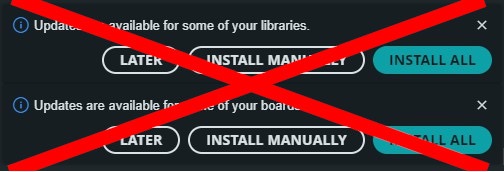
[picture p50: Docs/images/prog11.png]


13)	Click the Upload button to upload the sketch.

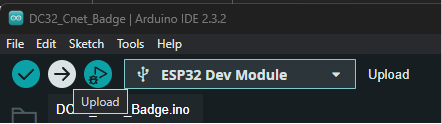
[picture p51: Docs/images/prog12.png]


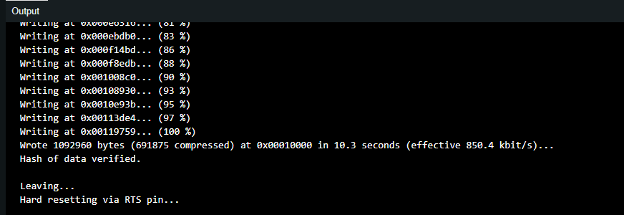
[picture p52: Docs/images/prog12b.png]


14)	If you want to see the debug messages click “Tools > Serial Monitor” and set the Serial Monitor speed to “921600”.

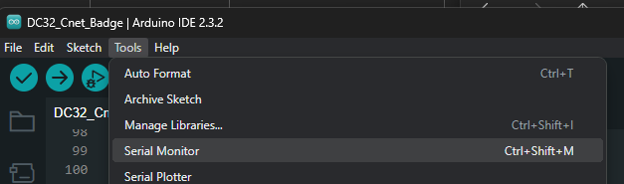
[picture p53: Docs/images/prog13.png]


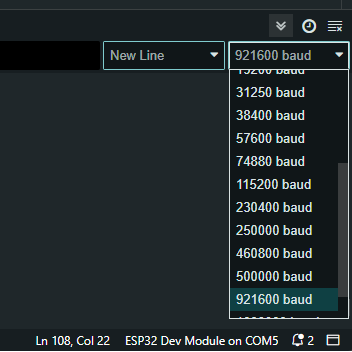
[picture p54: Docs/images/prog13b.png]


## Badge Operation

The power switch selects battery power or USB power. USB power will charge the battery. The battery must be sufficiently charged for battery operation. If the badge does not operate on battery power let it charge via USB. There is a battery “gas gauge” on the charge module that is viewable from the front of the board.

From your phone connect to Bluetooth device “FONY BITMAN”. Sound should play through the speakers and the LED strips should react to the music. The touch pads on the top front of the badge should act as music and volume controls.

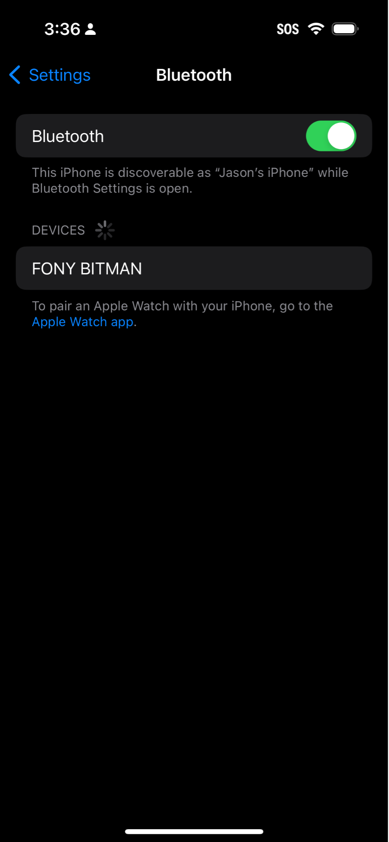
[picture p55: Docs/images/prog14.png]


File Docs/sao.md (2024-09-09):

## Cassette SAO

Assembling the Cassette SAO

1)	Front view

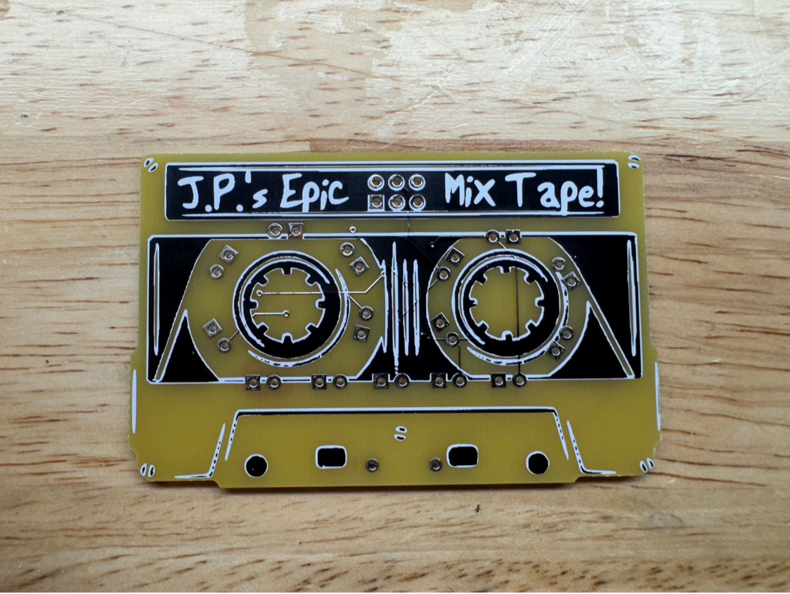
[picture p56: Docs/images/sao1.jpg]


2) Rear view

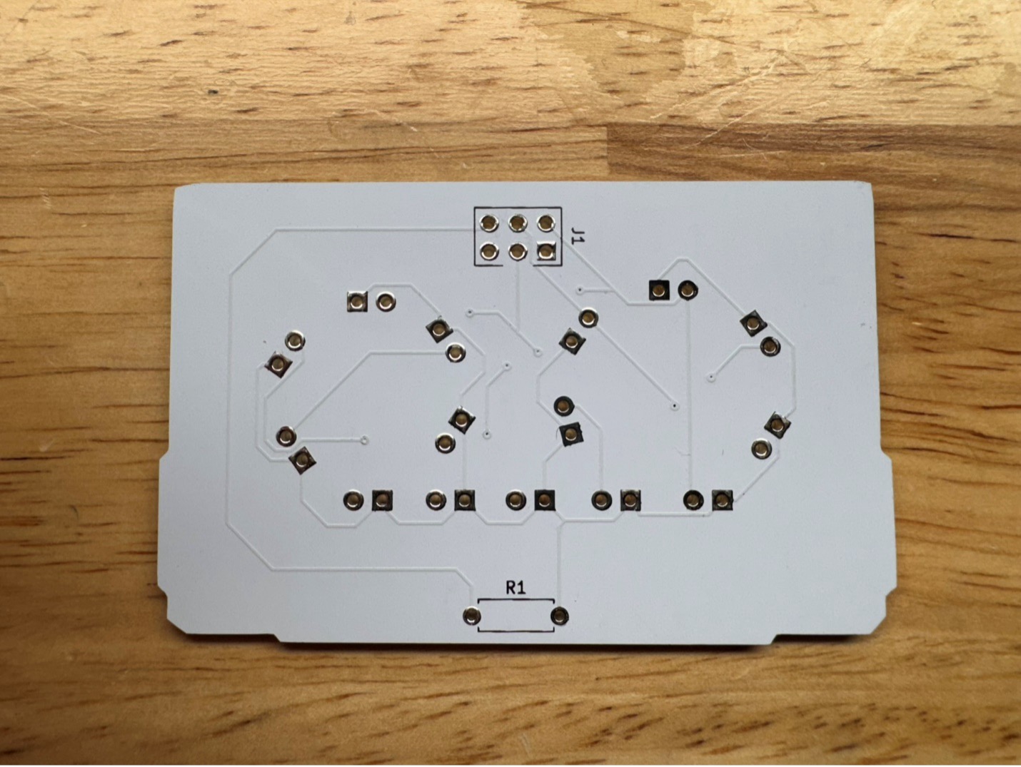
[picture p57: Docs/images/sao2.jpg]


3)	Solder R1 to the back of the SAO

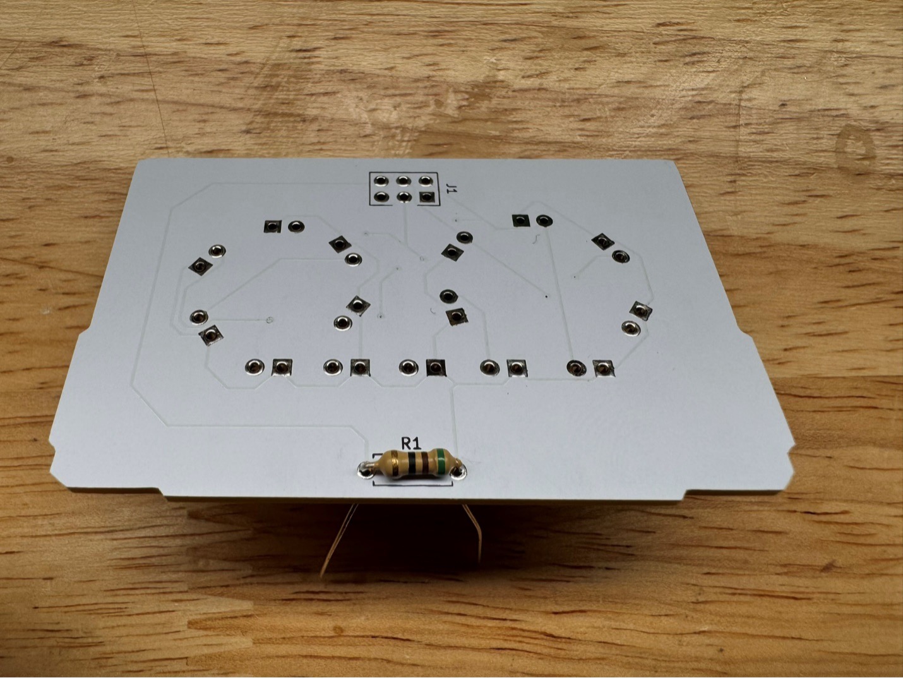
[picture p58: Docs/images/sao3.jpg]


4)	Trim the leads

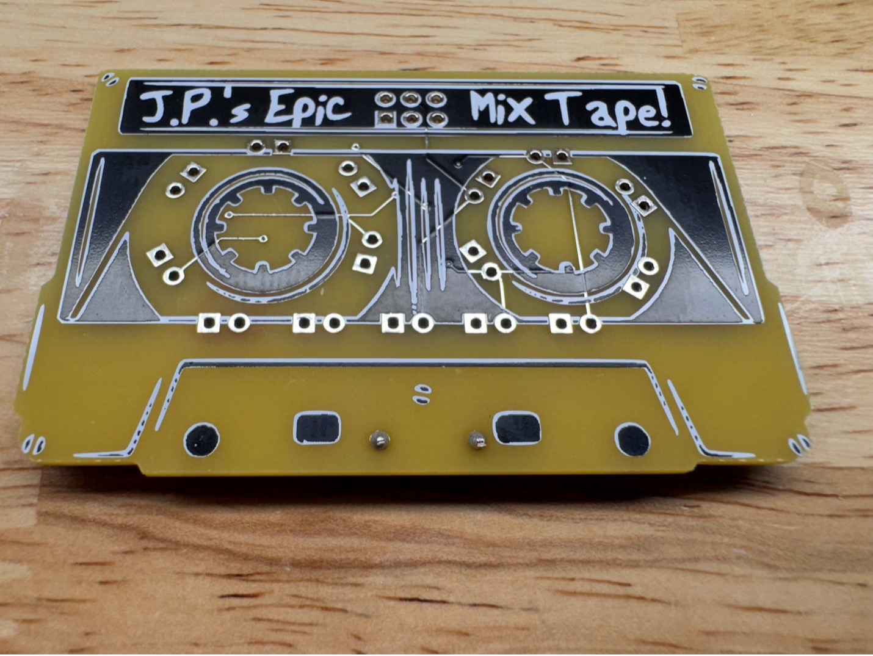
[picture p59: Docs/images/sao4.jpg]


5)	Solder the SAO header matching the notch orientation

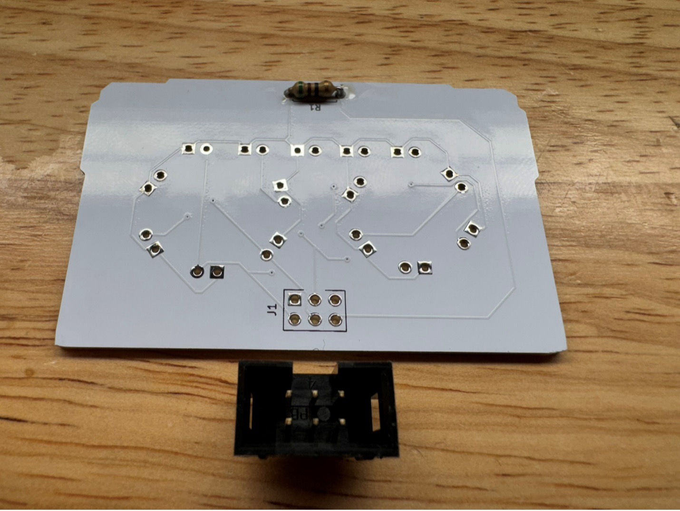
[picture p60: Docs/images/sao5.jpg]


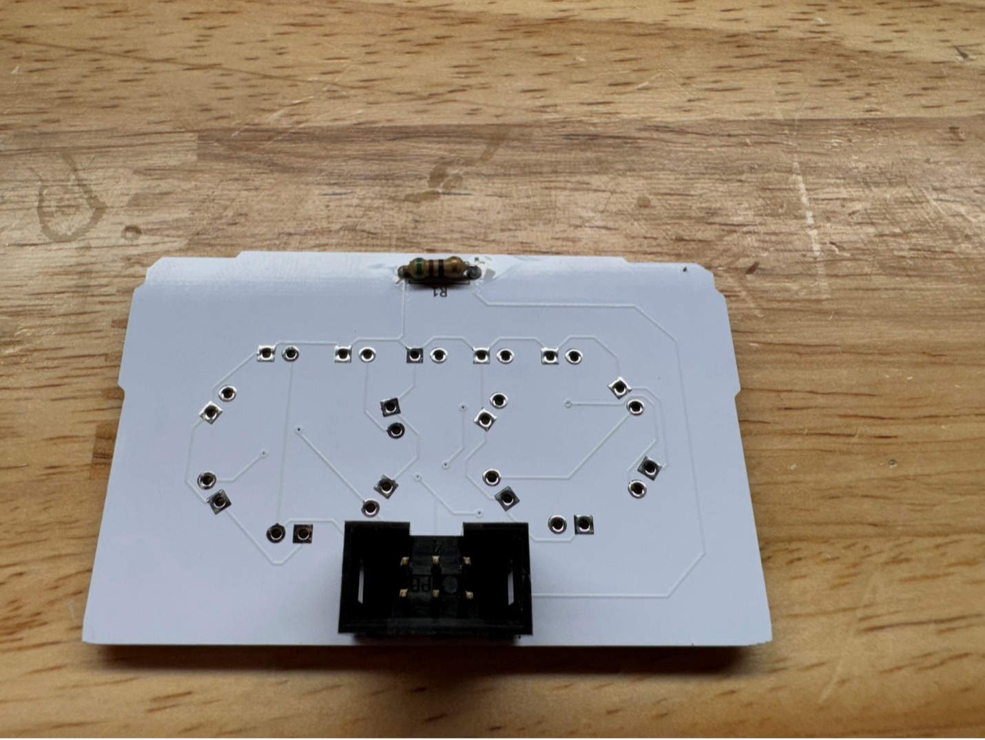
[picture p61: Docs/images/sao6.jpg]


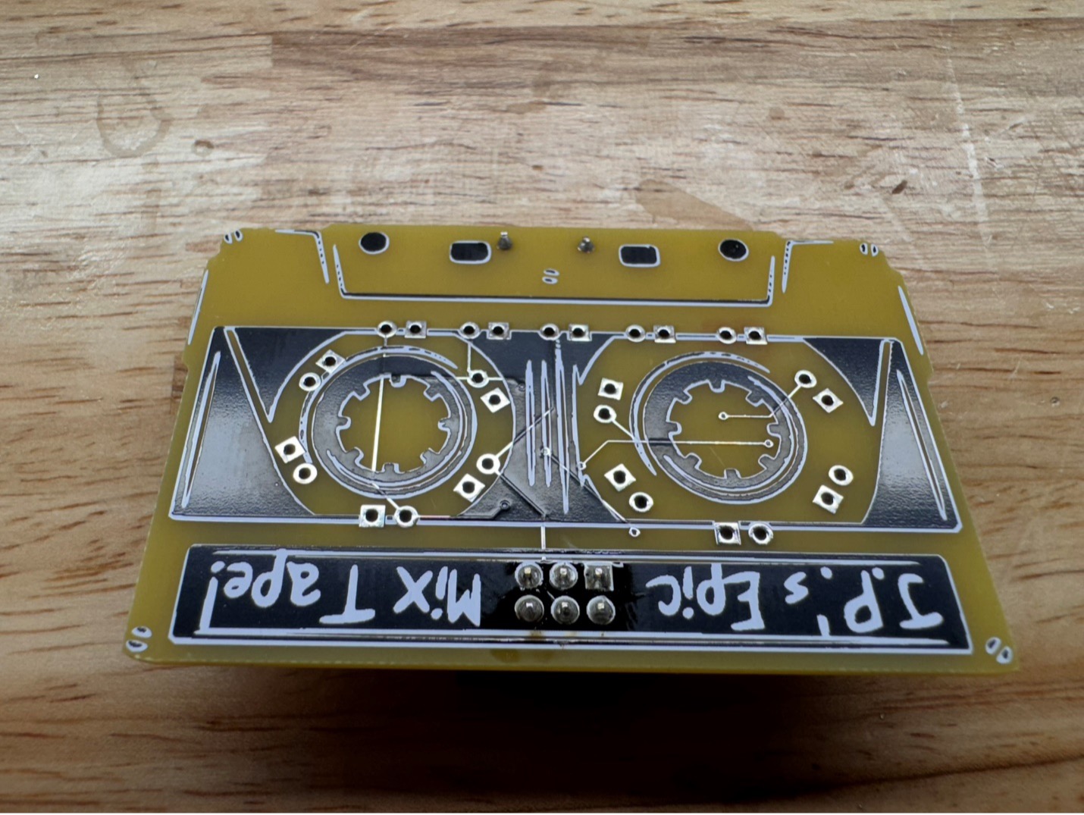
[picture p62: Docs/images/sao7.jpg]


6)	Solder the 15 rectangular LEDS noting the polarity – the shorter leads goes in the square holes, longer leads in the round holes

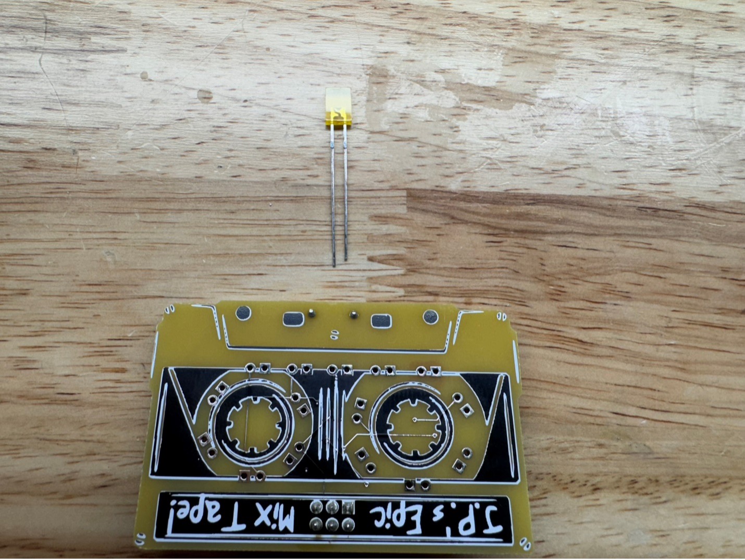
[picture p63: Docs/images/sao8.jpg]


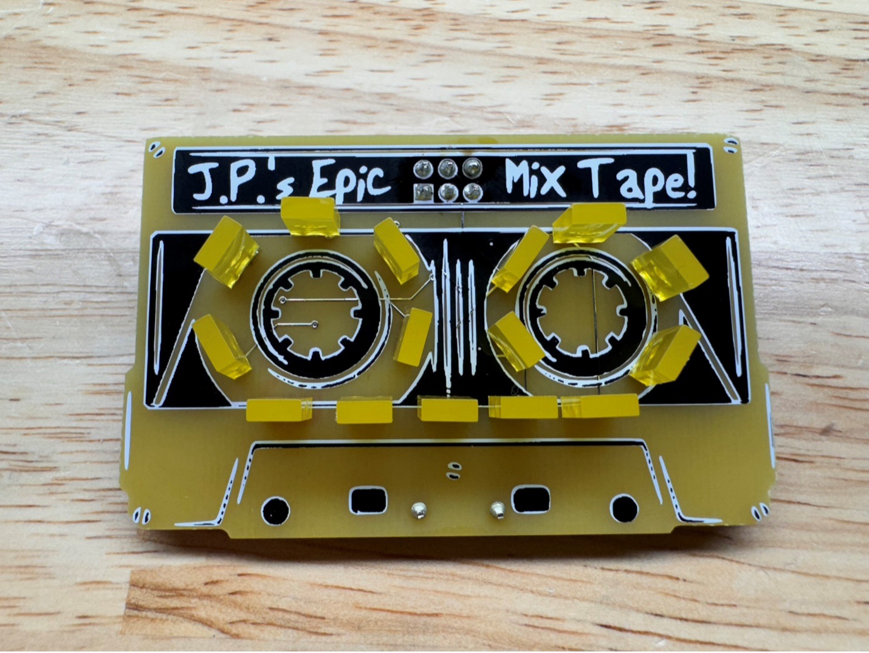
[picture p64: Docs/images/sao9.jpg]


7)	Trim the leads on the back



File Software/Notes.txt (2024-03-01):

ESP32 Board Manager:

https://espressif.github.io/arduino-esp32/package_esp32_index.json

Use esp32 by Espressif Systems version 2.0.12 (later versions have issues with poor bluetooth signal)

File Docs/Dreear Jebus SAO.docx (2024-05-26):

Dreear Jebus SAO

1) Locate the SAO PCB, LED ring, 6 pin rectangular header and row of pins


2) Snip apart 6 separate pins


3) Prop the SAO PCB face down and insert the 6 individual pins with the long side facing up


4) Solder the LED ring onto the 6 pins with the LEDs facing the back of the SAO PCB


5) Flip the SAO PCB over and solder the pins on the front


6) Solder the 6 pin rectangular header to the back, noting the notch orientation


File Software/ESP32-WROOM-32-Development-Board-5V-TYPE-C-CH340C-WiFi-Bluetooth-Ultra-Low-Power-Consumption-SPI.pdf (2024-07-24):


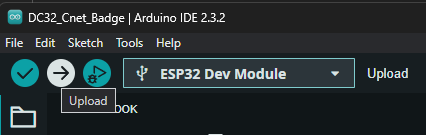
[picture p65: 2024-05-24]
Docs/Photos/Screenshot 2024-05-24 153301.png

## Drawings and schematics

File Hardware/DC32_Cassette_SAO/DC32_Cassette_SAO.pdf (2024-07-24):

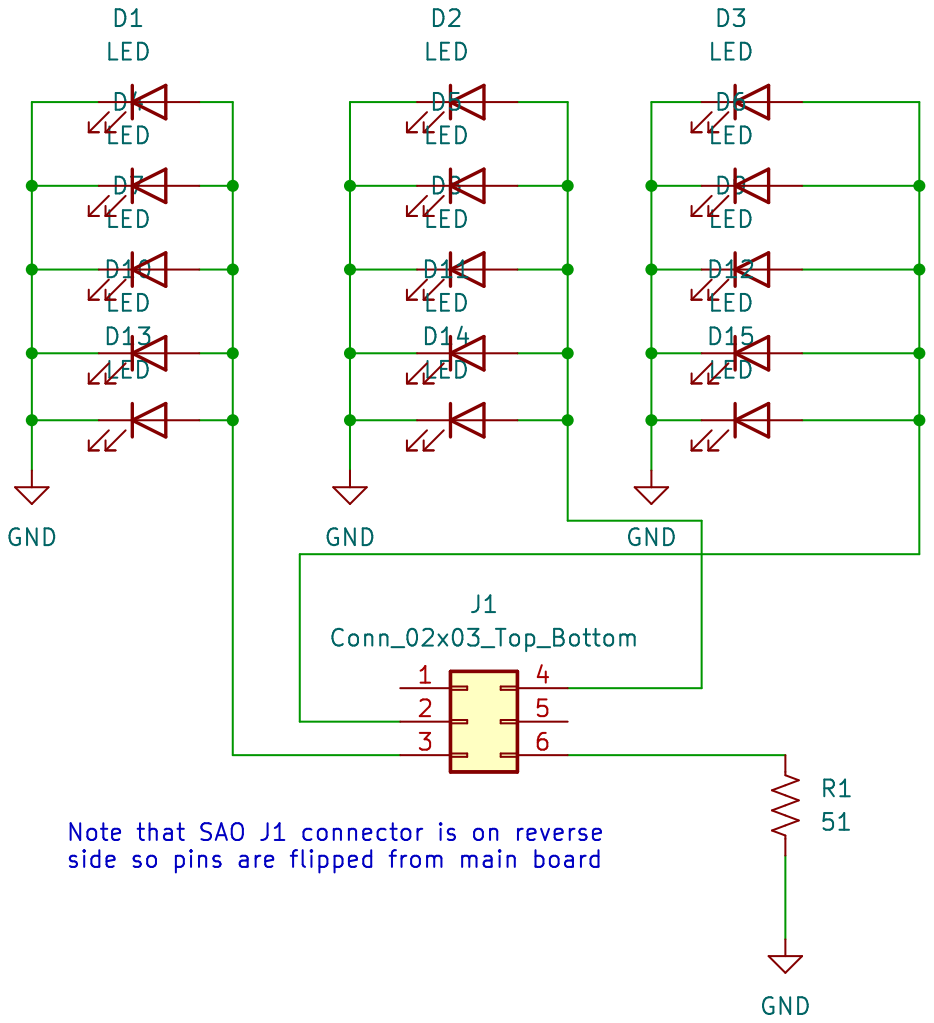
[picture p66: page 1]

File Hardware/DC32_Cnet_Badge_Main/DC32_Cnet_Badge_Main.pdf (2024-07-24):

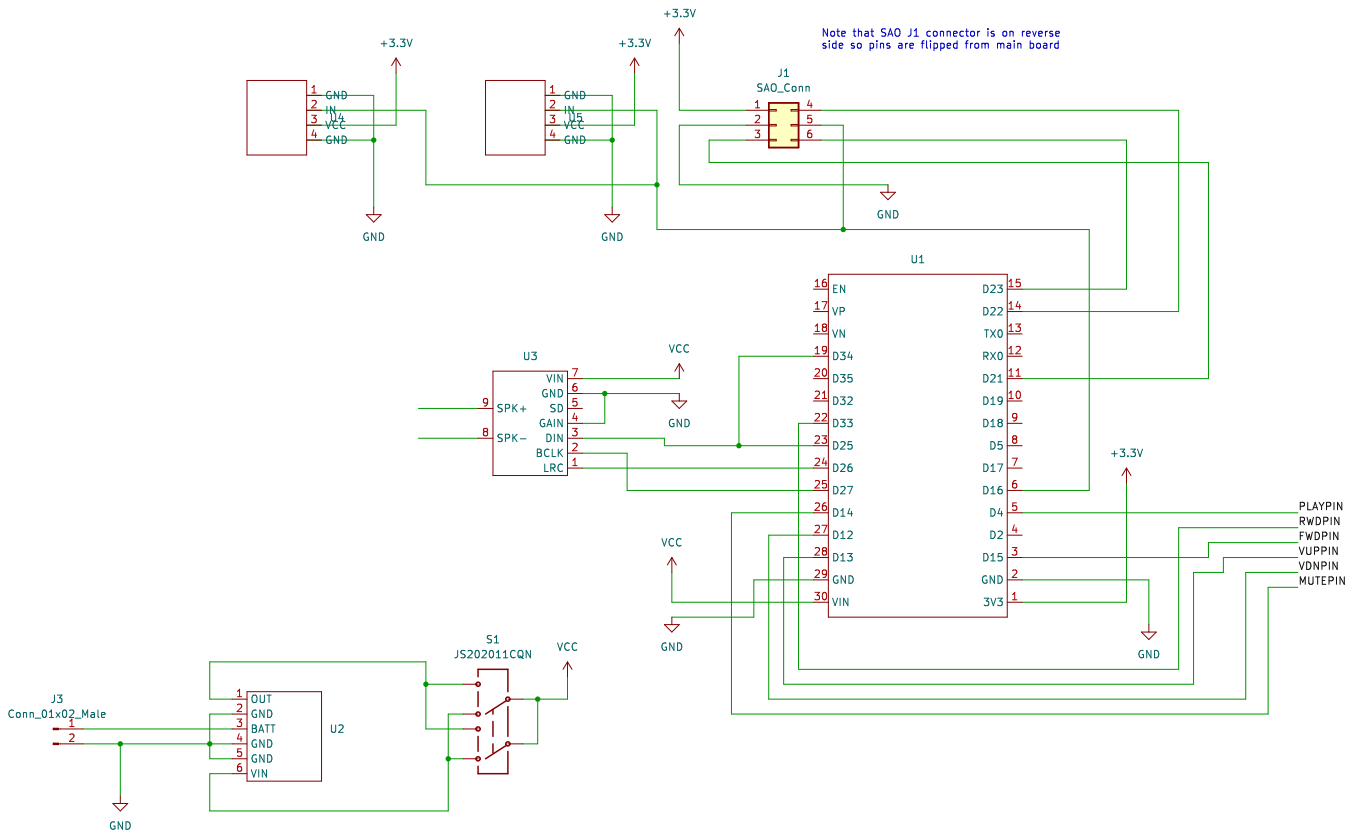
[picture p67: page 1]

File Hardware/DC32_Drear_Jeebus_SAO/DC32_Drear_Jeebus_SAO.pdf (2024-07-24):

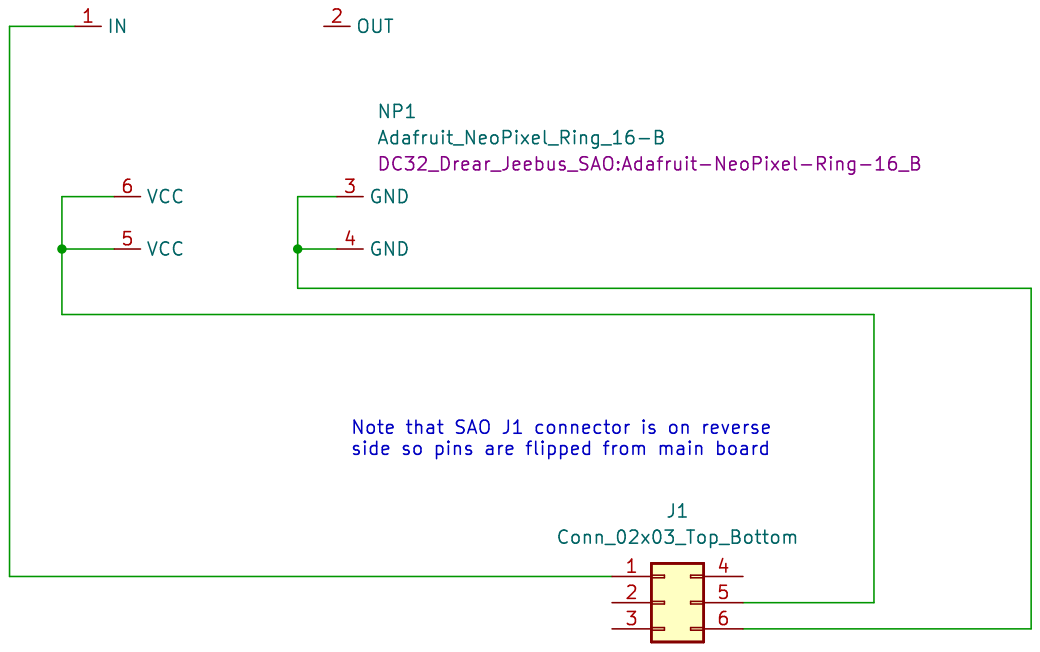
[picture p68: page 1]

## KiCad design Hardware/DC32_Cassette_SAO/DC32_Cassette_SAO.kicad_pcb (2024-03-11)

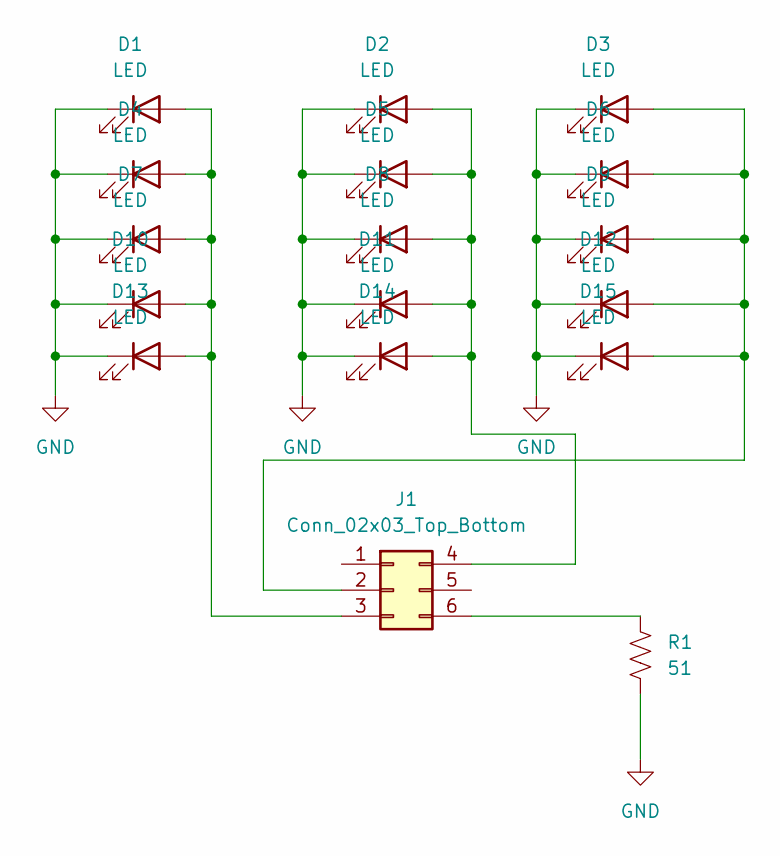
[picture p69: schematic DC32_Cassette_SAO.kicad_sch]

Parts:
D1, D2, D3, D4, D5, D6, D7, D8, D9, D10, D11, D12, D13, D14, D15: LED; LED_D3.0mm
J1: Conn_02x03_Top_Bottom; PinSocket_2x03_P2.54mm_Vertical_Tab
R1: 51; R_Axial_DIN0207_L6.3mm_D2.5mm_P7.62mm_Horizontal

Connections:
GND: D1.1 (K), D2.1 (K), D3.1 (K), D4.1 (K), D5.1 (K), D6.1 (K), D7.1 (K), D8.1 (K), D9.1 (K), D10.1 (K), D11.1 (K), D12.1 (K), D13.1 (K), D14.1 (K), D15.1 (K), R1.2
unnamed: D1.2 (A), D4.2 (A), D7.2 (A), D10.2 (A), D13.2 (A), J1.3
unnamed: D2.2 (A), D5.2 (A), D8.2 (A), D11.2 (A), D14.2 (A), J1.4
unnamed: D3.2 (A), D6.2 (A), D9.2 (A), D12.2 (A), D15.2 (A), J1.2
unnamed: J1.6, R1.1

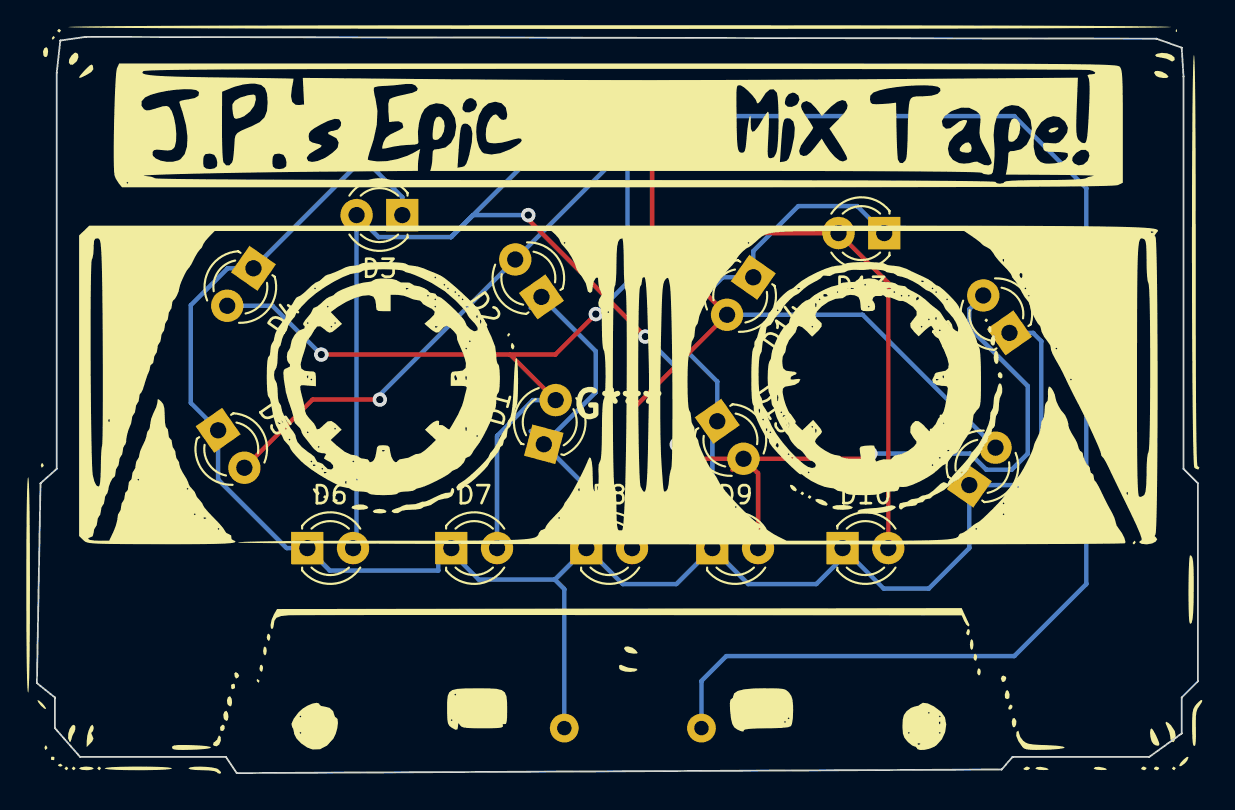
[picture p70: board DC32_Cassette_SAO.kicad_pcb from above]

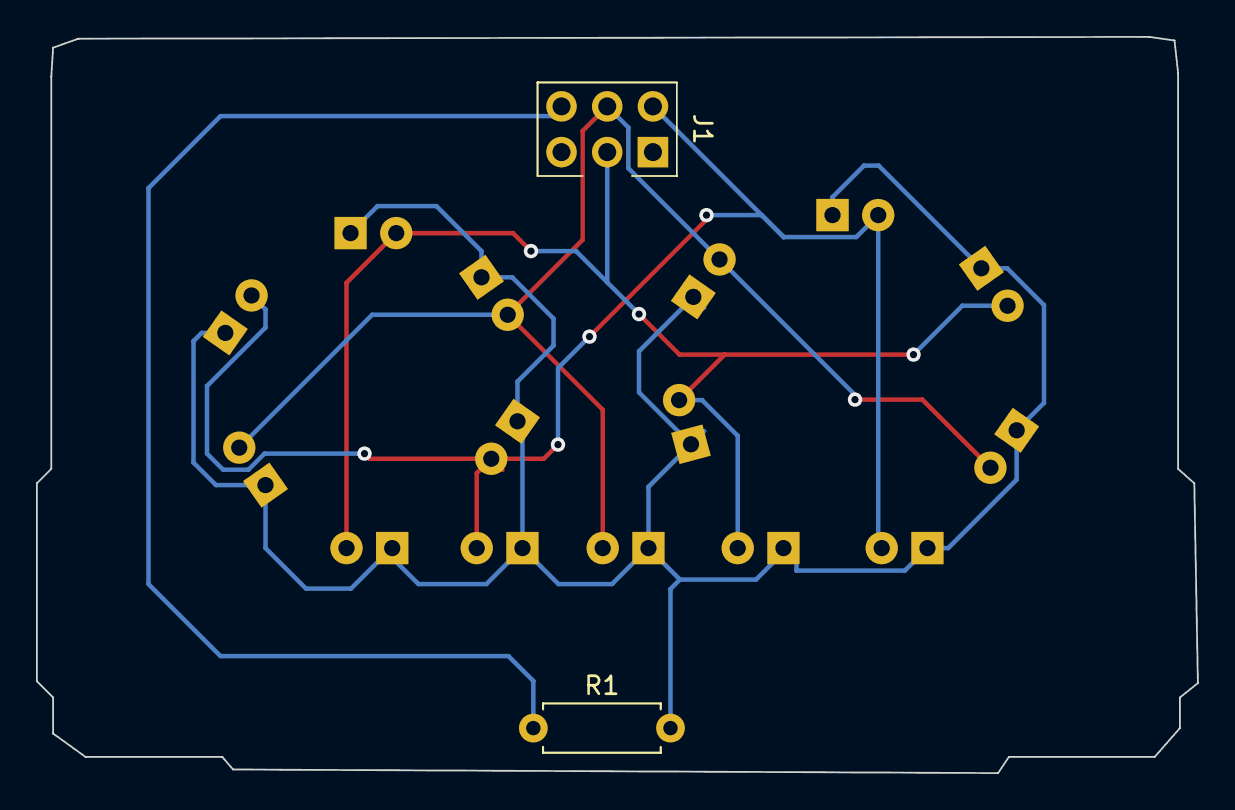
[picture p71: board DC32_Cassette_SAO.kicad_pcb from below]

Board: 2 copper layers, 64.5 x 40.9 mm, 17 parts (2 on the bottom side), 5 nets.

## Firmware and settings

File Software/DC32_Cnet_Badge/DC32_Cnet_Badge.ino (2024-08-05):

/*
@slash128
@compunetbiz
DEF CON 32
*/

//#include <BLEDevice.h>
#include <esp_bt.h>

#include <Adafruit_NeoPixel.h>
#define LEDPIN 16
#define NUMPIXELS 16
Adafruit_NeoPixel pixels = Adafruit_NeoPixel(NUMPIXELS, LEDPIN, NEO_GRB + NEO_KHZ800);


#include "BluetoothA2DPSink.h"
BluetoothA2DPSink a2dp_sink;

#define SENSORPIN 34
#define PLAYPIN 4
#define RWDPIN 33
#define FWDPIN 15
#define VDNPIN 12
#define VUPPIN 13
#define MUTEPIN 14
#define PLAY 1
#define PAUSE 0
bool playButton = 0;
bool rwdButton = 0;
bool fwdButton = 0;
bool vdnButton = 0;
bool vupButton = 0;
bool muteButton = 0;
bool playState = PAUSE;
int audioState = 0;
const int touchThresholdPlay = 20;
const int touchThresholdRwd = 20;
const int touchThresholdFwd = 20;
const int touchThresholdVdn = 20;
const int touchThresholdVup = 20;
const int touchThresholdMute = 20;
const int touchDelay = 1000;
int currVolume = 0;
int prevVolume = 0;
const int volStep = 10;
#define UNMUTED 1
#define MUTED 0
bool muteState = UNMUTED;
bool btConnected = false;
#define PRESSED 1
#define NOTPRESSED 0


#define CASSPIN_A 21
#define CASSPIN_B 22
#define CASSPIN_C 23
int prevCassPin = 21;
int currCassPin = 23;


uint32_t prevMillis = 0;
uint32_t lastPlayDebounceTime = 0;
uint32_t lastRwdDebounceTime = 0;
uint32_t lastFwdDebounceTime = 0;
uint32_t lastVdnDebounceTime = 0;
uint32_t lastVupDebounceTime = 0;
uint32_t lastMuteDebounceTime = 0;

uint8_t touchSumPlay = 0;
uint8_t touchAvgPlay = 0;
uint8_t countPlay = 0;
uint8_t touchSumRwd = 0;
uint8_t touchAvgRwd = 0;
uint8_t countRwd = 0;
uint8_t touchSumFwd = 0;
uint8_t touchAvgFwd = 0;
uint8_t countFwd = 0;
uint8_t touchSumVdn = 0;
uint8_t touchAvgVdn = 0;
uint8_t countVdn = 0;
uint8_t touchSumVup = 0;
uint8_t touchAvgVup = 0;
uint8_t countVup = 0;
uint8_t touchSumMute = 0;
uint8_t touchAvgMute = 0;
uint8_t countMute = 0;



int outputValue = 0;
int rememberOutputValue;
int randNumber;
int counter = 0;
int loopCounter = 0;


void getTouchButtons();
uint32_t colorPicker(byte colorPos);
void ledBars(int currVolLevel);
void cassetteSAOPlay();
void cassetteSAORewind();
void debug();


void setup() {
	pixels.begin();
	randomSeed(analogRead(0));
	Serial.begin(921600);

	i2s_pin_config_t my_pin_config = {
		.bck_io_num = 27,
		.ws_io_num = 26,
		.data_out_num = 25,
		.data_in_num = I2S_PIN_NO_CHANGE
	};

	a2dp_sink.set_pin_config(my_pin_config);
	a2dp_sink.start("FONY BITMAN");

	esp_ble_tx_power_set(ESP_BLE_PWR_TYPE_ADV, ESP_PWR_LVL_P3);

	pinMode(PLAYPIN, INPUT_PULLUP);
	pinMode(RWDPIN, INPUT_PULLUP);
	pinMode(FWDPIN, INPUT_PULLUP);
	pinMode(VDNPIN, INPUT_PULLUP);
	pinMode(VUPPIN, INPUT_PULLUP);
	pinMode(MUTEPIN, INPUT_PULLUP);

	pinMode(CASSPIN_A, OUTPUT);
	pinMode(CASSPIN_B, OUTPUT);
	pinMode(CASSPIN_C, OUTPUT);

}


void loop() {

	getTouchButtons();
	ledBars(currVolume); // is there a way to alter the LED bars behavior based on currVolume - challenge anyone?
	cassetteSAOPlay();
	debug();  // for debugging - duh :)

}




void getTouchButtons() {

	unsigned long currMillis = millis();
	
	if (touchRead(PLAYPIN) < touchThresholdPlay) {
		touchSumPlay += touchRead(PLAYPIN);
		countPlay += 1;
		if (currMillis - lastPlayDebounceTime > touchDelay) {
			lastPlayDebounceTime = currMillis;
			touchAvgPlay = touchSumPlay / countPlay;
			touchSumPlay = 0;
			countPlay = 0;
			if (touchAvgPlay < touchThresholdPlay) {
				
				// If it's still below the threshold, set the boolean flag
				playButton = PRESSED;
				
				} else {
				playButton = NOTPRESSED;
			}
			} else {
			// If the variable is not below the threshold, reset the boolean flag
			playButton = NOTPRESSED;
		}
	}


	if (playState == PAUSE && playButton == PRESSED) {
		currVolume = a2dp_sink.get_volume();
		a2dp_sink.set_volume(currVolume);
		a2dp_sink.play();
		playState = PLAY;
		playButton = NOTPRESSED;
	}

	if (playState == PLAY && playButton == PRESSED) {
		currVolume = a2dp_sink.get_volume();
		a2dp_sink.set_volume(currVolume);
		a2dp_sink.pause();
		playState = PAUSE;
		playButton = NOTPRESSED;
	}


	if (touchRead(RWDPIN) < touchThresholdRwd) {
		touchSumRwd += touchRead(RWDPIN);
		countRwd += 1;
		if (currMillis - lastRwdDebounceTime > touchDelay) {
			lastRwdDebounceTime = currMillis;
			touchAvgRwd = touchSumRwd / countRwd;
			touchSumRwd = 0;
			countRwd = 0;
			if (touchAvgRwd < touchThresholdRwd) {
				
				// If it's still below the threshold, set the boolean flag
				rwdButton = PRESSED;
				
				} else {
				rwdButton = NOTPRESSED;
			}
			} else {
			// If the variable is not below the threshold, reset the boolean flag
			rwdButton = NOTPRESSED;
		}
	}

	if (rwdButton == PRESSED) {
		currVolume = a2dp_sink.get_volume();
		a2dp_sink.set_volume(currVolume);
		a2dp_sink.previous();
		rwdButton = NOTPRESSED;
	}


	if (touchRead(FWDPIN) < touchThresholdFwd) {
		touchSumFwd += touchRead(FWDPIN);
		countFwd += 1;
		if (currMillis - lastFwdDebounceTime > touchDelay) {
			lastFwdDebounceTime = currMillis;
			touchAvgFwd = touchSumFwd / countFwd;
			touchSumFwd = 0;
			countFwd = 0;
			if (touchAvgFwd < touchThresholdFwd) {
				
				// If it's still below the threshold, set the boolean flag
				fwdButton = PRESSED;
				
				} else {
				fwdButton = NOTPRESSED;
			}
			} else {
			// If the variable is not below the threshold, reset the boolean flag
			fwdButton = NOTPRESSED;
		}
	}


	if (fwdButton == PRESSED) {
		currVolume = a2dp_sink.get_volume();
		a2dp_sink.set_volume(currVolume);
		a2dp_sink.next();
		fwdButton = NOTPRESSED;
	}


	if (touchRead(VDNPIN) < touchThresholdVdn) {
		touchSumVdn += touchRead(VDNPIN);
		countVdn += 1;
		if (currMillis - lastVdnDebounceTime > touchDelay) {
			lastVdnDebounceTime = currMillis;
			touchAvgVdn = touchSumVdn / countVdn;
			touchSumVdn = 0;
			countVdn = 0;
			if (touchAvgVdn < touchThresholdVdn) {
				
				// If it's still below the threshold, set the boolean flag
				vdnButton = PRESSED;
				
				} else {
				vdnButton = NOTPRESSED;
			}
			} else {
			// If the variable is not below the threshold, reset the boolean flag
			vdnButton = NOTPRESSED;
		}
	}

	if (vdnButton == PRESSED) {
		currVolume = a2dp_sink.get_volume();
		currVolume -= volStep;
		if (currVolume < 0) {
			currVolume = 0;
		}
		a2dp_sink.set_volume(currVolume);
		vdnButton = NOTPRESSED;
	}


	if (touchRead(VUPPIN) < touchThresholdVup) {
		touchSumVup += touchRead(VUPPIN);
		countVup += 1;
		if (currMillis - lastVupDebounceTime > touchDelay) {
			lastVupDebounceTime = currMillis;
			touchAvgVup = touchSumVup / countVup;
			touchSumVup = 0;
			countVup = 0;
			if (touchAvgVup < touchThresholdVup) {
				
				// If it's still below the threshold, set the boolean flag
				vupButton = PRESSED;
				
				} else {
				vupButton = NOTPRESSED;
			}
			} else {
			// If the variable is not below the threshold, reset the boolean flag
			vupButton = NOTPRESSED;
		}
	}

	if (vupButton == PRESSED) {
		currVolume = a2dp_sink.get_volume();
		currVolume += volStep;
		if (currVolume > 255) {
			currVolume = 255;
		}
		a2dp_sink.set_volume(currVolume);
		vupButton = NOTPRESSED;
	}


	if (touchRead(MUTEPIN) < touchThresholdMute) {
		touchSumMute += touchRead(MUTEPIN);
		countMute += 1;
		if (currMillis - lastMuteDebounceTime > touchDelay) {
			lastMuteDebounceTime = currMillis;
			touchAvgMute = touchSumMute / countMute;
			touchSumMute = 0;
			countMute = 0;
			if (touchAvgMute < touchThresholdMute) {
				
				// If it's still below the threshold, set the boolean flag
				muteButton = PRESSED;
				
				} else {
				muteButton = NOTPRESSED;
			}
			} else {
			// If the variable is not below the threshold, reset the boolean flag
			muteButton = NOTPRESSED;
		}
	}

	if (muteState == UNMUTED && muteButton == PRESSED) {
		prevVolume = a2dp_sink.get_volume();
		currVolume = 0;
		a2dp_sink.set_volume(currVolume);
		muteState = MUTED;
		muteButton = NOTPRESSED;
	}

	if (muteState == MUTED && muteButton == PRESSED) {
		currVolume = prevVolume;
		a2dp_sink.set_volume(currVolume);
		muteState = UNMUTED;
		muteButton = NOTPRESSED;
	}

}


uint32_t colorPicker(byte colorPos) {
	colorPos = 255 - colorPos;
	if (colorPos < 85) {
		return pixels.Color(255 - colorPos * 3, 0, colorPos * 3, 0);
	}
	if (colorPos < 170) {
		colorPos -= 85;
		return pixels.Color(0, colorPos * 3, 255 - colorPos * 3, 0);
	}
	colorPos -= 170;
	return pixels.Color(colorPos * 3, 255 - colorPos * 3, 0, 0);
}


void ledBars(int currVolLevel) {
	
	int sensorValue;
	counter = 0;

	for (int i = 0; i < 100; i++) {
		sensorValue = map(analogRead(SENSORPIN), 0, 2048, 0, 100);
		if (sensorValue > 100) counter++;
	}

	if (map(counter, 10, 60, 80, 80) > outputValue) outputValue = map(counter, 00, 40, 0, 40);
	else if (loopCounter % 2 == 0) outputValue -= 1;

	if (outputValue < 0) outputValue = 0;
	if (outputValue > 60) outputValue = 60;

	if (loopCounter % 100 == 0) randNumber = random(255);
	loopCounter++;

	for (int i = 0; i < NUMPIXELS; i++) {
		pixels.setPixelColor(i, pixels.Color(0, 0, 0, 255));
	}

	if (rememberOutputValue != outputValue) {
		for (int i = 60; i > (60 - outputValue) || (outputValue == 20 && i == 0); i--) {
			pixels.setPixelColor(i, colorPicker((randNumber)&255));
		}
		
		pixels.show();
	}

	rememberOutputValue = outputValue;
}


void cassetteSAOPlay() {

	audioState = a2dp_sink.get_audio_state();

	uint32_t cassMoveLEDsMillis = 150;
	uint32_t currMillis = millis();
	if((currMillis - prevMillis > cassMoveLEDsMillis) && (audioState == 2)) {

		digitalWrite(prevCassPin, LOW);
		digitalWrite(currCassPin, HIGH);

		prevCassPin--;
		if(prevCassPin < 21) {
			prevCassPin = 23;
		}

		currCassPin--;
		if(currCassPin < 21) {
			currCassPin = 23;
		}

		prevMillis = currMillis;
	}

}


void cassetteSAORewind() { // WIP to implement a rewind animation, is there something to key on in the a2dp_sink library for rewind state - challenge anyone?

	audioState = a2dp_sink.get_audio_state();

	uint32_t cassMoveLEDsMillis = 75;
	uint32_t currMillis = millis();
	if((currMillis - prevMillis > cassMoveLEDsMillis) && (audioState == 2)) {

		digitalWrite(prevCassPin, HIGH);
		digitalWrite(currCassPin, LOW);

		prevCassPin--;
		if(prevCassPin < 21) {
			prevCassPin = 23;
		}

		currCassPin--;
		if(currCassPin < 21) {
			currCassPin = 23;
		}

		prevMillis = currMillis;
	}

}

void debug() {

	// Check the current BLE power level (might be useful for debugging)
	int32_t currentLevel = esp_ble_tx_power_get(ESP_BLE_PWR_TYPE_ADV);
	Serial.print("Current BLE Power Level: ");
	Serial.println(currentLevel); // This will likely print 5 (corresponding to +3dBm)
	
	Serial.println("audioState = " + String(audioState));
	
	Serial.println("PlayPin = " + String(touchRead(PLAYPIN)));
	Serial.println("RwdPin = " + String(touchRead(RWDPIN)));
	Serial.println("FwdPin = " + String(touchRead(FWDPIN)));
	Serial.println("VDnPin = " + String(touchRead(VDNPIN)));
	Serial.println("VUpPin = " + String(touchRead(VUPPIN)));
	Serial.println("MutePin = " + String(touchRead(MUTEPIN)));
}

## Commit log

2024-02-19 Incremental Commit
    [DC32_Cnet_Badge_Main.kicad_pcb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]
2024-03-01 Reverted to ESP32 2.0.12
    ESP32 2.0.14 has issues with Bluetooth signal quality.
    [DC32_Cnet_Badge_Main.kicad_pcb]
2024-03-11 PCB updates
    [DC32_Cassette_SAO-B_Cu.gbr, DC32_Cassette_SAO-B_Mask.gbr, DC32_Cassette_SAO-B_Paste.gbr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]
2024-03-18 New PCB Designs
2024-06-10 Updated ReadMe with new battery connectors
2024-07-24 Updated schematics and generated PDFs
    [DC32_Cassette_SAO.kicad_sch, DC32_Cnet_Badge_Main.kicad_sch, DC32_Drear_Jeebus_SAO.kicad_sch]
